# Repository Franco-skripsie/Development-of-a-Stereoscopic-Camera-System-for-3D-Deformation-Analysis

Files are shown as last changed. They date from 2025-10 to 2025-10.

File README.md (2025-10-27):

# Development of a Stereoscopic Camera System for 3D Deformation Analysis

This repository contains the hardware designs (CAD) and software for a custom stereoscopic camera system designed for 3D deformation analysis. The system uses two synchronized Raspberry Pi Camera Module 3 units to capture stereo image pairs, which can be used to compute depth information and analyze 3D deformation.

## Project Report
This repository supports the Mechatronic Project 478 final report. For a complete understanding of the project's background, design methodology, hardware selection, software algorithms, and full results, please read the complete PDF report.

View the Full Project Report `25866095-DuPlessis.pdf`

## Table of Contents

- [Overview](#overview)
- [Hardware Components](#hardware-components)
- [Software Components](#software-components)
- [Prerequisites](#prerequisites)
- [Installation](#installation)
- [Usage Guide](#usage-guide)
  - [1. Capturing Calibration Images](#1-capturing-calibration-images)
  - [2. Stereo Calibration](#2-stereo-calibration)
  - [3. 3D Dot Pattern Calibration](#3-3d-dot-pattern-calibration)
  - [4. Stereo Rectification and Disparity Mapping](#4-stereo-rectification-and-disparity-mapping)
- [Repository Structure](#repository-structure)
- [Calibration Patterns](#calibration-patterns)
- [Contributing](#contributing)
- [License](#license)

## Overview

This stereoscopic camera system is designed to:
- Capture synchronized stereo image pairs using dual Raspberry Pi Camera Module 3
- Perform accurate stereo calibration using both chessboard patterns and custom 3D dot patterns
- Generate disparity maps for depth estimation
- Enable 3D deformation analysis through precise depth measurements

The system features custom 3D-printed enclosures for camera protection, adjustable mounting, and optimized camera placement for stereoscopic imaging.

## Hardware Components

### Camera System
- **2x Raspberry Pi Camera Module 3** - High-resolution cameras with autofocus
- **Raspberry Pi 5** - Main controller for dual camera operation
- **Custom 3D-Printed Enclosures** (CAD files included):
  - `Camera Enclosure/` - Left and right camera housings with backplates
  - `RPi5 Enclosure/` - Protective enclosure for Raspberry Pi 5
  - `Base to Mounting Rail Connector/` - Hardware mounting system

### Calibration Equipment
- **Chessboard Pattern** - 9×6 inner corners, 14.5mm squares (for standard calibration)
- **Custom 3D Calibration Plate** - 264 white dots on black background:
  - Grid A: 143 dots (12×12 grid minus one) at -1mm depth
  - Grid B: 121 dots (11×11 grid) at reference plane (0mm)
  - 1.2mm dot diameter, 5mm spacing within grids
  - 1mm depth separation between grids for 3D calibration

## Software Components

The `Code/` directory contains Python scripts for the complete stereo vision pipeline:

### Calibration Scripts

1. **`stereo_calibration_collector.py`**
   - Interactive stereo image capture tool
   - Synchronized capture from both cameras
   - Live preview with crosshair alignment
   - Anti-flicker settings for LED lighting
   - Manual and timer capture modes
   - Quality validation and autofocus control

2. **`stereo_calibrate.py`**
   - Standard stereo calibration using chessboard pattern
   - Individual camera intrinsic calibration
   - Stereo extrinsic calibration (rotation & translation)
   - Outputs multiple formats: NPZ & JSON
   - Generates detailed calibration reports

3. **`stereo_calibrate_3d_dots.py`**
   - Advanced 3D calibration using custom dot pattern
   - Non-planar calibration for improved accuracy
   - Uses two grids at different depths (1mm separation)
   - Leverages proven chessboard calibration as initial estimates

### Dot Detection and Processing

4. **`dot_identifier.py`**
   - Automated white dot detection on black background
   - Processes custom 3D calibration plate images
   - Uses HoughCircles detection with white center validation
   - K-means clustering for column identification
   - Outputs sorted point arrays for Grid A and Grid B
   - Generates visualization and CSV export

5. **`live_dot_tuner.py`**
   - Interactive GUI for tuning dot detection parameters
   - Real-time parameter adjustment with visual feedback
   - HoughCircles parameter optimization
   - White center threshold tuning
   - Export optimized parameters for batch processing

### Stereo Processing

6. **`simple_stereo_rectify.py`**
   - Stereo image rectification
   - Epipolar line visualization
   - SGBM (Semi-Global Block Matching) disparity computation
   - Generates disparity maps (grayscale and color-coded)
   - Outputs rectified stereo pairs

## Prerequisites

### Hardware Requirements
- Raspberry Pi 5 (or compatible)
- 2× Raspberry Pi Camera Module 3
- Raspberry Pi SSD Kit (Recommended)
- Calibration patterns (printed or displayed)

### Software Requirements
- Python 3.7+
- OpenCV (cv2) with Python bindings
- NumPy
- Picamera2 (for Raspberry Pi Camera Module 3)
- Matplotlib
- Pandas
- scikit-learn
- Tkinter (for GUI tools)

## Installation

### 1. System Setup

```bash
# Update system packages
sudo apt-get update
sudo apt-get upgrade

# Install system dependencies
sudo apt-get install python3-pip python3-opencv
sudo apt-get install python3-picamera2
```

### 2. Python Dependencies

```bash
# Install required Python packages
pip3 install numpy opencv-python matplotlib pandas scikit-learn

# For GUI tools
sudo apt-get install python3-tk
```

### 3. Clone Repository

```bash
git clone https://github.com/Franco-skripsie/Development-of-a-Stereoscopic-Camera-System-for-3D-Deformation-Analysis.git
cd Development-of-a-Stereoscopic-Camera-System-for-3D-Deformation-Analysis/Code
```

## Usage Guide

### 1. Capturing Calibration Images

Use `stereo_calibration_collector.py` to capture synchronized stereo image pairs:

```bash
python3 stereo_calibration_collector.py
```

**Key Controls:**
- `c` - Capture stereo image pair
- `t` - Toggle between manual and timer modes
- `a` - Trigger autofocus on both cameras
- `l` - Lock white balance and autofocus
- `r` - Restore proven camera settings
- `q` - Quit

**Tips:**
- Capture 20-30 image pairs at different angles and distances
- Ensure the calibration pattern is clearly visible in both cameras
- Use the crosshair for alignment
- Vary the position and orientation of the pattern

### 2. Stereo Calibration

After capturing calibration images, perform stereo calibration:

```bash
python3 stereo_calibrate.py
```

This will:
- Detect chessboard corners in all image pairs
- Calibrate individual camera intrinsics
- Compute stereo extrinsic parameters (R, T)
- Generate rectification matrices
- Save calibration data: `stereo_calib.npz`, `stereo_calib.json`
- Create `calibration_report.txt` with detailed results

### 3. 3D Dot Pattern Calibration

For advanced calibration using the custom 3D dot pattern:

#### Step 3a: Detect and Sort Dots

```bash
# Basic usage
python3 dot_identifier.py --image path/to/image.png

# With custom parameters
python3 dot_identifier.py \
  --image calib/left001.png \
  --output results/left001 \
  --hough-min-dist 25 \
  --hough-param1 50 \
  --hough-param2 15 \
  --white-threshold 180
```

**Output Files:**
- `*_gridA_points.npy` - Grid A dot coordinates (143 points)
- `*_gridB_points.npy` - Grid B dot coordinates (121 points)
- `*_dots.csv` - All detected dots with grid/column/row info
- `*_visualization.png` - Visual verification of detection

#### Step 3b: Tune Detection Parameters (Optional)

Use the interactive tuner to optimize detection:

```bash
python3 live_dot_tuner.py --image path/to/image.png
```

The GUI allows real-time adjustment of:
- Minimum distance between circles
- Edge detection threshold
- Circle detection threshold
- Radius range
- White center threshold

#### Step 3c: 3D Calibration

After processing dot identification for stereo pairs:

```bash
python3 stereo_calibrate_3d_dots.py
```

This performs:
- Non-planar calibration using two grids at different depths
- Uses chessboard calibration as initial estimates
- Outputs: `3d_plate_stereo_calib.npz`, `3d_plate_stereo_calib.json`

### 4. Stereo Rectification and Disparity Mapping

Process stereo images to generate depth information:

```bash
python3 simple_stereo_rectify.py
```

**Configuration** (edit script):
```python
CALIB_FILE = "stereo_calib.npz"           # Calibration data
LEFT_IMAGE = "capture/left001.png"         # Input left image
RIGHT_IMAGE = "capture/right001.png"       # Input right image
OUTPUT_DIR = "results"                     # Output directory
```

**Output Files:**
- `rect_left.png` / `rect_right.png` - Rectified images
- `rect_left_lines.png` / `rect_right_lines.png` - Images with epipolar lines
- `epipolar_comparison.png` - Side-by-side view
- `disparity_gray.png` - Grayscale disparity map
- `disparity_color.png` - Color-coded disparity map

## Repository Structure

```
Development-of-a-Stereoscopic-Camera-System-for-3D-Deformation-Analysis/
│
├── Code/                                    # Python software
│   ├── stereo_calibration_collector.py      # Image capture tool
│   ├── stereo_calibrate.py                  # Chessboard calibration
│   ├── stereo_calibrate_3d_dots.py          # 3D dot pattern calibration
│   ├── dot_identifier.py                    # Dot detection and sorting
│   ├── live_dot_tuner.py                    # Interactive parameter tuning
│   └── simple_stereo_rectify.py             # Rectification and disparity
│
├── Camera Enclosure/                        # 3D printable camera housings
│   ├── Camera_Backplate.ipt                 # Camera mounting backplate
│   ├── Camera_Enclosure_Left.ipt            # Left camera enclosure
│   └── Camera_Enclosure_Right.ipt           # Right camera enclosure
│
├── RPi5 Enclosure/                          # Raspberry Pi 5 enclosure
│   ├── RPi5_Enclosure_Bottom.ipt            # Bottom enclosure part
│   └── RPi5_Enclosure_Top.ipt               # Top enclosure part
│
├── Base to Mounting Rail Connector/         # Mounting hardware
│   └── Base_Mounting_Rail_Connector.ipt     # Rail mounting connector
│
└── README.md                                # This file
```

**Note:** `.ipt` files are Autodesk Inventor part files. Open them with Autodesk Inventor or convert to STL for 3D printing.

## Calibration Patterns

### Chessboard Pattern
- **Size:** 9×6 inner corners
- **Square Size:** 15mm
- **Purpose:** Standard stereo calibration
- **Usage:** Print on flat, rigid surface or display on screen

### Custom 3D Dot Pattern
- **Total Dots:** 264 (143 + 121)
- **Grid A:** 12×12 grid (minus one dot at column 12, row 2)
  - Depth: -1mm (behind Grid B)
  - 143 dots total
- **Grid B:** 11×11 grid
  - Depth: 0mm (reference plane)
  - 121 dots total
- **Dot Properties:**
  - Diameter: 1.2mm
  - Color: White dots on black background
  - Spacing: 5mm within same grid
  - Depth separation: 1mm between grids
- **Purpose:** Advanced 3D calibration with non-planar target

## Workflow Summary

1. **Setup Hardware**
   - Assemble cameras in 3D-printed enclosures
   - Mount on stable base with appropriate baseline distance
   - Connect to Raspberry Pi 5

2. **Capture Calibration Images**
   - Use `stereo_calibration_collector.py`
   - Capture 20-30 chessboard image pairs
   - Optionally capture custom 3D dot pattern images

3. **Perform Calibration**
   - Run `stereo_calibrate.py` for standard calibration
   - Or process dots and run `stereo_calibrate_3d_dots.py` for 3D calibration

4. **Process Stereo Images**
   - Use `simple_stereo_rectify.py` to:
     - Rectify stereo pairs
     - Compute disparity maps
     - Analyze depth information

5. **Analyze Results**
   - Review calibration reports for accuracy
   - Examine disparity maps
   - Use depth data for deformation analysis

## Calibration Quality Indicators

### Good Calibration:
- RMS reprojection error < 0.5 pixels
- Horizontal epipolar lines in rectified images
- Smooth, continuous disparity maps
- Baseline distance matches physical measurement

### Signs of Poor Calibration:
- RMS error > 1.0 pixel
- Misaligned epipolar lines
- Noisy or discontinuous disparity maps
- Need more image pairs at varied angles

## Troubleshooting

### Camera Issues
- **Blank/dark images:** Check lighting, adjust exposure in `stereo_calibration_collector.py`
- **Sync issues:** Ensure both cameras are properly initialized
- **Focus problems:** Use autofocus (`a` key) or restore proven settings (`r` key)

### Calibration Issues
- **Low accuracy:** Capture more image pairs with better coverage
- **Pattern not detected:** Improve lighting, ensure pattern is flat and clearly visible
- **High RMS error:** Check for motion blur, improve pattern quality

### Dot Detection Issues
- **Too few/many dots detected:** Use `live_dot_tuner.py` to optimize parameters
- **Incorrect clustering:** Adjust `--hough-min-dist` parameter
- **False positives:** Increase `--white-threshold` value

## Contributing

Contributions are welcome. This is an open-source academic project, and improvements to the calibration algorithms, hardware designs, or documentation are appreciated. Please feel free to fork the repository, make changes, and open a pull request.

### How to Contribute:
1. Fork the repository
2. Create a feature branch (`git checkout -b feature/improvement`)
3. Make your changes
4. Test thoroughly with actual hardware
5. Commit with clear messages (`git commit -am 'Add feature'`)
6. Push to branch (`git push origin feature/improvement`)
7. Open a Pull Request

### Areas for Improvement:
- Additional calibration pattern support
- Real-time disparity computation optimisation
- Enhanced GUI for calibration workflow
- Automated quality assessment
- Integration with 3D reconstruction pipelines

## License

This project is licensed under the MIT License. See the (`LICENSE`) file for details.

## Acknowledgments

This stereoscopic camera system was developed for 3D deformation analysis research. The system combines:
- Standard stereo calibration techniques (Zhang's method)
- Custom 3D calibration patterns for improved accuracy
- Raspberry Pi Camera Module 3 for high-resolution imaging
- OpenCV for computer vision processing

---

**Last Updated:** 2025

**Hardware:** Raspberry Pi 5 + 2× Pi Camera Module 3  
**Software:** Python 3 + OpenCV + Picamera2

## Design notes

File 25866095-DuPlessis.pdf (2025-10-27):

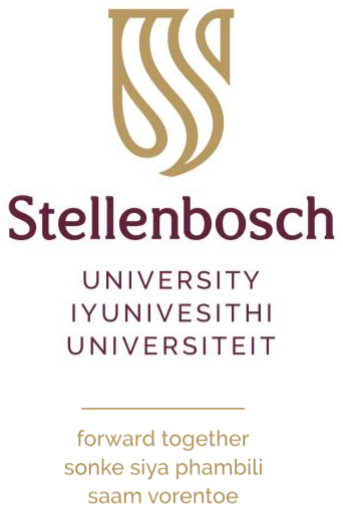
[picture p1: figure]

Department of Mechanical and Mechatronic Engineering Stellenbosch University
Tel: +27 21 808 4204 | www.eng.sun.ac.za
Private Bag X1, Matieland, 7602, South Africa

Copyright © 2025 Stellenbosch University All rights reserved

# Development of a Stereoscopic Camera System for 3D Deformation Analysis

## Mechatronic Project 478 Final Report

## F du Plessis

25866095

## Supervisor: Prof RP Theart

## October 2025

i

## Executive Summary

Title of Project
Development of a stereoscopic camera system for 3D deformation analysis.
Objectives
Objectives will focus on delivering a cost-effective final camera system that can be used for further research and development into the field of 3D digital image correlation (DIC):
1. To design and construct a cost-effective stereoscopic camera system suitable for researching and developing an in-house 3D DIC algorithm.
2. To develop a calibration procedure that is robust, user-friendly, and time-efficient, thus aiding in the overall experience when using the camera system.
3. To create an intuitive user interface that facilitates access to and execution of all relevant camera system functions.
What is current practice and what are its limitations?
The current systems available for conducting 3D DIC are from various corporate companies and are expensive. The systems are also closed-source in nature and do not provide the user with the ability to modify the software to cater to their specific needs. The software used has a poor user interface and a steep learning curve. This makes it overly complicated for most tasks that these systems encounter.
What is new in this project?
The project aims to develop a fully functional, open-source stereoscopic camera system optimised for Digital Image Correlation (DIC). The project offers a practical and scalable platform for experimentation, further research, and development. The project will feature stereo camera calibration, with an additional focus on using only one photo pair to complete the calibration procedure.
If the project is successful, how will it make a difference?
The system will provide the Mechanical and Mechatronic Department of Stellenbosch University with a portable and cost-effective stereoscopic camera system. The implementation of a user-friendly user interface will mitigate the steep learning curve, thereby ensuring that users can start capturing samples for material analysis quickly and easily. The camera system will allow the Mechanical and Mechatronic Department to develop and test their own fully open-source 3D DIC setup.

ii

What are the risks to the project being a success? Why is it expected to be successful?
The risks are a limited budget and time frame. The project's complexity is high and is associated with restricted access to the workshop of the Mechanical and Mechatronic Engineering Department. The project is expected to be successful due to the implementation of rigorous cost and time management. Additionally, careful scheduling of manufacturing will significantly contribute to the project's success.
What contributions have/will other students made/make?
N/A
Which aspects of the project will carry on after completion and why?
The project establishes a robust foundation for the Mechanical and Mechatronic Department to develop an in-house 3D DIC algorithm. It aims to deliver a fully functional, cost-effective, open-source 3D DIC system, designed to be accessible and adaptable for research and educational purposes. The calibration procedure developed can be applied to any other stereoscopic camera systems used at Stellenbosch University.
What arrangements have been/will be made to expedite continuation?
The system’s code and hardware designs will be uploaded to GitHub, ensuring it remains fully open-source and accessible for future development. Additionally, the hardware will utilise off-the-shelf components to streamline assembly and enhance scalability.

iii

## Plagiarism declaration

I have read and understand the Stellenbosch University Policy on Plagiarism and the definitions of plagiarism and self-plagiarism contained in the Policy [Plagiarism: The use of the ideas or material of others without acknowledgement, or the re-use of one's own previously evaluated or published material without acknowledgement or indication thereof (self-plagiarism or text-recycling)].

I also understand that direct translations are plagiarism, unless accompanied by an appropriate acknowledgement of the source. I also know that verbatim copy that has not been explicitly indicated as such, is plagiarism.

I know that plagiarism is a punishable offence and may be referred to the University's Central Disciplinary Committee (CDC) who has the authority to expel me for such an offence.

I know that plagiarism is harmful for the academic environment and that it has a negative impact on any profession.

Accordingly all quotations and contributions from any source whatsoever (including the internet) have been cited fully (acknowledged); further, all verbatim copies have been expressly indicated as such (e.g. through quotation marks) and the sources are cited fully.

I declare that, except where a source has been cited, the work contained in this assignment is my own work and that I have not previously (in its entirety or in part)
submitted it | for grading | in this | module/assignment | or another
module/assignment.

I declare that have not allowed, and will not allow, anyone to use my work (in paper, graphics, electronic, verbal or any other format) with the intention of passing it off as his/her own work.

I know that a mark of zero may be awarded to assignments with plagiarism and also that no opportunity be given to submit an improved assignment.

Signature

Name: | Franco du Plessis | Student no: 25866095
Date: | 09 March 2025

iv

## ECSA Exit Level Outcomes

ECSA Outcomes Assessed in this Module

ECSA Outcomes | Chapter Addressed
GA 1. Problem solving: Demonstrate competence to identify, assess, formulate and solve convergent and divergent engineering problems creatively and innovatively. | Chapter 1, 3, 4, 5
GA 2. Application of scientific and engineering knowledge: Demonstrate competence to apply knowledge of mathematics, basic science and engineering sciences from first principles to solve engineering problems. | Chapter 2, 3, 4, 5
GA 3. Engineering Design: Demonstrate competence to perform creative, procedural and non-procedural design and synthesis of components, systems, engineering works, products or processes. | Chapter 3, 4
GA 5. Engineering methods, skills and tools, including Information Technology: Demonstrate competence to use appropriate engineering methods, skills and tools, including those based on information technology. | Chapter 2, 3, 4, 5
GA 6. Professional and technical communication: Demonstrate competence to communicate effectively, both orally and in writing, with engineering audiences and the community at large. | Entire report
GA 8. Individual, Team and Multidisciplinary Working: Demonstrate competence to work effectively as an individual, in teams and in multi-disciplinary environments | Entire report
GA 9. Independent Learning Ability: Demonstrate competence to engage in independent learning through well-developed learning skills. | Entire report

v

## Table of contents

Page

vi

vii

C.2 Safety Report | 61
Appendix D Wiring Diagram of Relay Control | 68
Appendix E | Chessboard Pattern Calibration Report | 69
Appendix F | Single-Image Calibration Report | 70

viii

## List of figures

Page
Figure 1: Tensile Test Specimen Before and After Conducting a Tensile Test. ...... 6 Figure 2: The Setup for 2D and 3D DIC is Illustrated with Grayscale Observed Image on the Left and the Post-processed Results of the DIC on the

Figure 19: Chessboard Square Measured (left), Chessboard Fastened to Wooden

ix

Figure 28: Single Image of 3D Calibration Plate (left), Grayscale Conversion of
Image (right) | 46
Figure 29: Gaussian Blur Applied (left), Adaptive Thresholding Applied (right). . 47
Figure 30: Morphological Opening (left) and Closing (right) Applied | 47
Figure 31: Detected Circles Organised into Two Grids | 48
Figure 32: Gantt Chart of Completed Project | 59
Figure 33: Relay Control Circuit | 68
Figure 34: Chessboard Stereo Calibration Report | 69
Figure 35: Single-Image Calibration Report | 70

x

## List of tables

Page

## 1 Introduction

## 1.1 Background

Tensile testing is a fundamental and widely adopted method for evaluating the mechanical properties of materials under uniaxial tensile load. It provides critical insights into how a material behaves when subjected to stretching forces, including properties such as yield strength, ultimate tensile strength, and elongation (Saba et al., 2018). Although the behaviour of materials can be described mathematically to some extent, variations in composition, structure, and processing often lead to complex responses that cannot be fully captured through theoretical models alone. As such, tensile testing serves as an essential experimental approach for accurately characterising these properties and validating material performance in real-world applications.

This method utilises machines like the MTS Criterion C44 to apply a force to the sample, which can be monitored using the built-in load meter. During tensile testing, various methods can be used to collect point data that will be used to determine the material characteristics (AbouelNour et al., 2024). One of the most common methods employed uses a strain gauge that is physically attached to the specimen while performing a tensile test (Elmardi & Khayal, 2024).

Although strain gauges are a cost-effective solution to determining the properties of a material, they are only capable of measuring single-plane properties. Additionally, they must be physically attached to the point of measurement on the specimen to collect data (“Strain gauges”, n.d.) . This is undesirable when working with specimens whose surfaces are irregular or fragile, as it can lead to adhesion problems. Strain gauges are also sensitive to temperature changes and have a limited measurement range due to linear elongation (Shanmukha, 2017).

A solution to these limitations is to employ a method that does not require physical connections to the point of measurement, can accurately collect data of the specimen in multiple planes and remains a low-cost solution.

One possible solution is to use 3D Digital Image Correlation (DIC) analysis. DIC is a non-contact, image-based methodology used for measuring surface geometry, deformation, and strain, first established in the 1980s (Holmes et al, 2023). The sample is covered in a unique speckle pattern that is vital for the software to track any changes to the sample. DIC records a sequence of high-resolution images as the sample deforms, using mathematical algorithms to track surface displacement and extract deformation data. To achieve 3D analysis of a sample, the digital images are captured using a stereoscopic camera setup

(Zaremba & Nitkiewicz, 2024). This is achieved by using two cameras slightly angled toward each other, mimicking human vision. This setup creates a 3D representation of the sample’s surface, enabling full-field deformation analysis.

This analysis method requires three components: a stereoscopic camera setup, DIC software and a reliable calibration method. Currently, commercially available DIC systems, such as those from Correlated Solutions and LaVision, are prohibitively expensive, with costs exceeding R1 000 000. While the M&M Engineering Department at Stellenbosch University has two of these systems, access to these systems is limited. Concerns about potential damage to the equipment are a key reason for its infrequent use in undergraduate studies. The problematic and confusing user interface (UI) further emphasises the need for a new system. This highlights the need for a cost-effective, in-house developed alternative.

An open-source DIC system offers greater opportunities for researching innovative methods for conducting DIC and analysing speckle patterns. Full accessibility to the system is essential, enabling researchers to modify all relevant components as needed.

## 1.2 Problem Statement

The problem is that there is no accessible open-source stereoscopic camera system that allows accurate, low-cost 3D DIC analysis within the research and teaching environment.

## 1.3 Aim

The project will focus on designing and constructing a stereoscopic camera setup for conducting 3D DIC analysis. This setup will serve as a cost-effective alternative to the existing commercial systems while maintaining usability and accuracy.

The project aims to provide the Mechanical and Mechatronic Engineering Department with an additional DIC setup accessible to students from undergraduate to PhD levels. The scope includes developing the stereoscopic camera setup and designing a highly accurate and intuitive calibration procedure. This calibration process will be guided by intuitive and user-friendly interfaces, ensuring ease of use. Additionally, this system will be able to extract disparity maps of the analysed image scene. However, the development of the 3D DIC algorithm itself falls outside the scope of this project.

Unlike current commercial systems, this setup will feature an intuitive interface that simplifies operation and reduces the need for extensive training. As an in-house developed system, it offers flexibility for continuous improvement while reducing long-term costs associated with purchasing and maintaining commercial equipment. The open-source nature of the project enables anyone worldwide to access, build upon, and enhance the system, fostering collaborative innovation.

## 1.4 Objectives

The project will be defined by three main objectives, each with its own sub-objectives.

1. Physical System:
a. Design and construct a stereoscopic camera system that fits within an area of approximately 1 m³
to reduce the system footprint while operating.
2. Calibration Procedure:
a. Develop and implement a stereo camera calibration procedure that creates an accurate representation of changes in depth within an image scene.
b. Create the calibration procedure in such a manner that it can be completed within approximately 120 seconds from initiation to completion.
3. Control Software:
a. Develop optimised, user-friendly interfaces for navigating or conducting tasks when using the camera system. These interfaces will control all functions, including calibrating the system, capturing and storing images, and creating disparity maps of image scenes for analysis and interpretation.

## 1.5 Limits and Exclusions

The project has defined limits and exclusions to establish clear boundaries within which it will be conducted. The camera system will focus on tracking samples with sizes closely aligned with existing tensile testing standards (“Standard & specimens for metals tensile test”, n.d.). As a result, the system will be limited to tracking samples between 50 mm and 150 mm in both length and width. Although the system is capable of monitoring samples outside of this range, the project scope will be limited to the dimensions as mentioned above. This is because most tensile testing done to calculate material properties is conducted on samples that follow the ASTM standard, which are approximately the same size (“Standard & specimens for metals tensile test”, n.d.) The project will not utilise high-speed cameras, and therefore, the project scope will exclude high-speed testing. The cameras will operate at a maximum frame rate of 45 frames per second (fps). The cameras are capable of operating at a maximum frame rate of 56 fps at a resolution of 2304 × 1296 pixels (“Camera - Raspberry Pi Documentation”, n.d.). The limit of 45 fps allows adequate room for processing in the background while capturing images.

The project must be completed within the academic year and will operate within a maximum hardware budget of R5 500. The development of a 3D DIC algorithm is excluded to ensure project completion within the given timeframe. The project scope will not include the connection made between the tensile tester and the camera system.

## 1.6 Motivation

The motivation to conduct this project stems from the need to develop an in-house 3D DIC setup for the Mechanical and Mechatronic Engineering Department at Stellenbosch University. The system significantly reduces the initial capital cost compared to current commercial systems. Transitioning from these expensive commercial systems will free the Mechanical and Mechatronic Department from being restricted to using only specific replacement parts, which are often tied to the commercial system. Additionally, this reduces downtime caused by waiting for internationally shipped parts, which also incur import taxes. Beyond cost reduction, this project offers flexibility and customisation, enabling continuous improvements and adaptation to future developments in 3D DIC technology. Furthermore, the project allows the department to replicate the system, facilitating scalability and broader use across different research groups. Ultimately, the project establishes a solid foundation for future advancements in the 3D DIC field, particularly in terms of the potential development of an in-house, custom-designed 3D DIC algorithm.

## 1.7 Structure of Report

The report will start with a literature study talking about the project background, relevant components and previous work done in Chapter 2. The hardware design will be discussed in Chapter 3, with the analysis and motivation for design choices. Chapter 4 will analyse the software design and flow of information needed to achieve the full functionality required. The results will be examined in Chapter 5, along with the testing procedures followed to obtain them.

## 1.8 AI Usage in Report

This project was completed with assistance from AI. The use of AI was responsible, and everything in this report is the author's own work, unless otherwise indicated. AI was employed to correct spelling errors, improve grammar, and enhance the flow of paragraphs. It was also utilised to aid in understanding and analysing open-source code and its interactions.

## 2 Literature review

This chapter reviews the background, literature and previous work regarding stereoscopic camera systems. The elements discussed in this chapter will focus on the aspects related to the relevant implementation of 3D DIC.

## 2.1 Stereo Vision Background

Stereoscopic camera systems utilise two or more spatially separated image sensors to capture the same scene from different viewpoints. This arrangement mimics human binocular vision and enables depth perception through the principle of triangulation (Perumal et al., 2021). The fundamental physical assumption is that a single point in the real world will project to distinct pixel locations in each camera’s image plane. The difference in these pixel positions, referred to as binocular disparity (as discussed in Section 2.4), is used to infer depth (Anzai & DeAngelis, 2010). This process, which reconstructs three-dimensional geometry from two-dimensional images, is known as stereo vision (as discussed in Section 2.3), and forms the basis of spatial measurements in three-dimensional Digital Image Correlation systems (as discussed in Section 2.2).

## 2.2 Digital Image Correlation

Digital Image Correlation (DIC) is a technique that utilises digital images to measure the deformation of objects under stress. This non-contact method is widely used in fields such as materials science and engineering because it provides detailed data without requiring physical contact with the object. It is accomplished by continuously analysing the differences between two sequentially captured images. In practical engineering applications, DIC is employed to measure the deformation of specimens, such as the tensile test specimen seen in Figure 1, during tensile testing. This is done for varies reasons such as conducting quality control on manufactured samples, predicting the performance of materials to aid in material selection, and to compare materials during research and development.

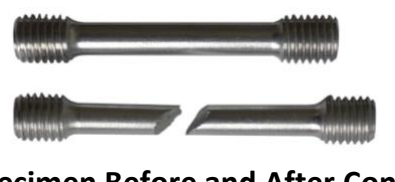
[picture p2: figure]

The DIC system captures images of the specimen’s surface at various stages as a controlled tensile force is applied. By analysing these images, DIC provides a full-field strain map that highlights how the material deforms, necks, or localisesstrain before failure. This detailed spatial data enables engineers to accurately

Figure 1: Tensile Test Specimen Before and After Conducting a Tensile Test.
Source: “Tensile test brittle deformation fracture”, 2021 determine critical mechanical properties, such as Young’s modulus, yield strength, and ultimate tensile strength. The DIC system requires data from the tensile tester, like tensile force, to conduct the deformation analysis. This creates a requirement for the camera system to be able to receive data from the tensile tester. The non-contact measurement capability of DIC ensures that the specimen remains unaltered during testing, thereby delivering reliable results necessary for material characterisation, product development, and safety assessment in real-world engineering scenarios.

DIC is primarily divided into two forms, 2D and 3D, both of which use a random speckle pattern during image analysis. The sample being analysed is covered in a random speckle pattern after the necessary surface preparations have been completed. The application of the speckle pattern is done using various methods like spray painting, spin coating and lithography, to name a few (Dong & Pan, 2017). The sample surface and background must have a high contrast to ensure optimal dot tracking conditions. This can be achieved by using a white background and black dots, for example. Consistent speckle size, typically 3-5 pixels in size, enhances spatial resolution, enabling more precise displacement measurements, especially when the sample is covered in an approximately equal distribution of white and black areas (“Fundamentals of Speckling for DIC”, 2023).

In DIC, the displacement of each speckle, represented by an individual point in the pattern, is measured as the distance it moves between consecutively captured images. The DIC software analyses this movement to determine the vector quantities of displacement. It tracks small regions of the image across successive frames by matching patterns to those in the reference image. This technique is applied across the entire image to monitor the displacement of all speckles during the deformation process. From this, normal, shear, and principal strains are determined. For 3D DIC, which measures depth and out-of-plane motion, two or more cameras are required to capture stereoscopic data (“Digital Image Correlation”, n.d.).

Two-dimensional DIC is limited to measuring in-plane deformations exclusively due to its single-camera setup. This approach is more straightforward and requires fewer computational resources compared to three-dimensional DIC. However, the technique is incapable of capturing out-of-plane displacements, which may result

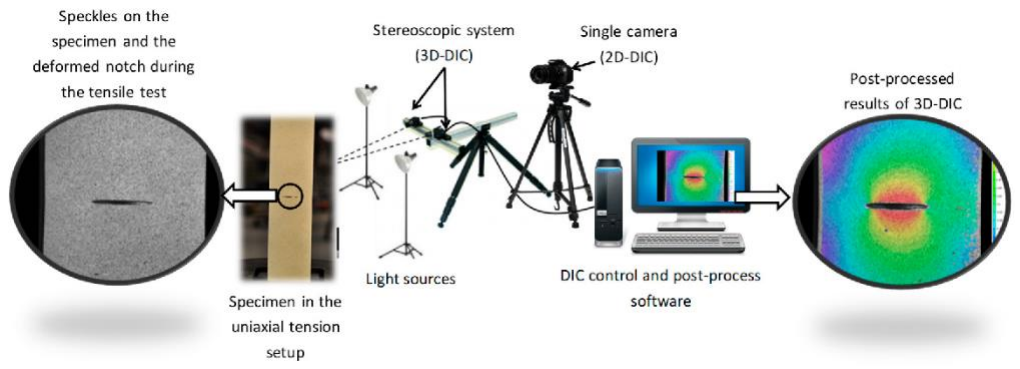
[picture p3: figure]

Figure 2: The Setup for 2D and 3D DIC is Illustrated with Grayscale Observed Image on the Left and the Post-processed Results of the DIC on the Right.

Source: “DIC and test set up”, 2018 in inaccuracies if the sample surface undergoes rotation or bending out of the plane (Sutton et al., 2008).

Three-dimensional DIC employs a multi-camera system to capture three-dimensional deformation, including out-of-plane movements, thereby facilitating more precise sample analysis. The intricacy of the setup necessitates meticulous and accurate calibration to attain optimal accuracy (Tiwari et al, 2007). The setup of 2D and 3D DIC can be seen in Figure 2, with an illustration of the elongation measured throughout the sample.

## 2.3 Stereo Vision Geometry

In a stereoscopic camera setup, the image measurements of each camera are given with respect to its own image coordinate system. To ensure accurate 3D spatial information, these measurements must be generalised to a single standard coordinate frame. A general representation of stereo vision geometry is shown in Figure 3, which illustrates the notation used in this report. To simplify calibration, the standard reference frame used by the system will be the same as the coordinate frame of the left camera.

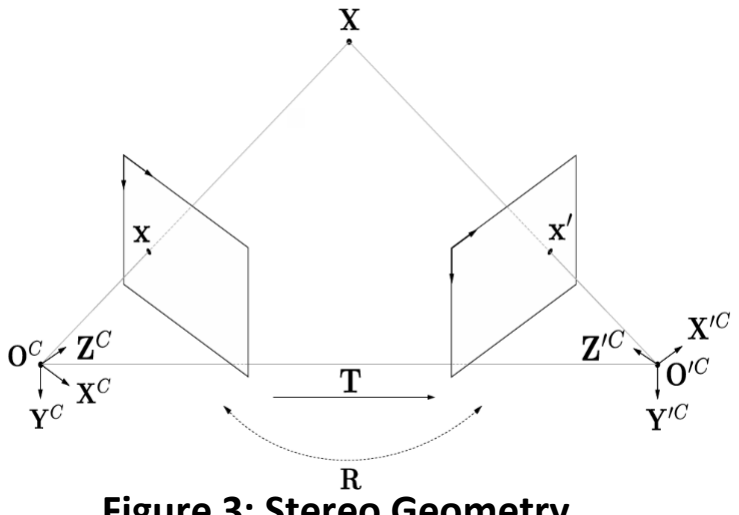
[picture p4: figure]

The centre of the left and right cameras’ optical sensors is defined as OC
and O′

C
respectively. Furthermore, the left camera’s coordinate system is indicated by X

C
,
Y

C
and Z

C
and has a real point X projected onto the image plane as x. Similarly, the right camera’s coordinate system is indicated by X′

C
, Y′

C
and Z′

C
and has a
projected point x’. Relative translation and relative rotation are indicated by T and R respectively. The relative rotation is the transformation that allows the alignment of one camera with another, expressed as a 3x3 matrix. The relative translation indicates the positional difference between the optical centres of the cameras, expressed as a 3D vector. These two parameters represent the extrinsic camera parameters and will be determined using stereo calibration. Baseline (B) is the distance between the centres of the two cameras’ optical sensors. The distance between the camera’s sensor and lens is known as the focal length (f),

Figure 3: Stereo Geometry

Source: “Generic representation of the stereo geometry”, 2017 measured in millimeters. Focal length can also be expressed in pixel units as fx and fy and is used to scale the world coordinates into the image plane.

## 2.4 Binocular Disparity

Binocular disparity is the horizontal offset between projections of the same 3D point onto two horizontally separated camera sensors. When you view a scene with two cameras, each camera sees the world from a slightly different angle. The difference in pixel coordinates of a feature between the left and right images is its disparity (Young, 2020).

To calculate the disparity (d) of pixels in an image, it must first be established which pixel in the image on the right matches a given pixel in the left image (“Depth Chapter 11”, n.d.). This can be completed using several methods, such as block matching (BM), semi-global block matching (SGBM), and feature-based matching (“OpenCV”, n.d.). In this report, SGBM will be used due to its increased accuracy and parameter tuning capabilities (“OpenCV”, n.d.). SGBM has a total of 11 parameters, compared to feature-based matching, which has five parameters, and block matching, which has two parameters. This is why SGBM was selected.

After the corresponding points have been identified, using SGBM, sub-pixel enhancement can be applied to boost depth precision (“OpenCV”, n.d.). The enhanced data can be used to calculate the disparity using Equation 2.1.

d = xL − xR | (2.1)

The left pixel’s horizontal location is represented by xL and the pixel on the right by xR. Thus, the disparity (d) is the difference between the two projected points on the image frame. After the disparity is calculated, the triangulation equation can be applied to compute the real-world depth of each point (“Depth Chapter 11”, n.d.).

Z =

f∙B d | (2.2)

In Equation 2.2, Z refers to the depth along the camera’s optical axis measured in milimeters.

## 2.5 Camera Calibration

To achieve an accurate correlation between 3D real-world points and 2D image points on an image, we must apply camera calibration. This process is characterised by calculating the intrinsic and extrinsic camera parameters. Intrinsic parameters describe the internal optics of the camera, including focal length (fx, fy) and principal point (cx, cy), both of which is measured in pixels.

Extrinsic parameters, on the other hand, define the camera’s position in the real world relative to a reference coordinate system, like its rotation and translation (Hartley & Zisserman, 2004).

Calibration is done to account for and correct the imperfections found in the cameras’ lenses and sensors, ensuring accurate measurements. Accurate calibration ensures a highly accurate representation of real-world properties.

A calibration object is used to define real-world coordinates of 3D points, such as a checkerboard or calibration plate, with known dimensions. The cameras capture the images of the calibration plate and find the pixel coordinates (u, v) for each 3D point. The intrinsic and extrinsic camera parameters are calculated using a camera calibration algorithm.

### 2.5.1 Intrinsic Parameters

The focal length (measured in pixels) indicates the distance between the optical centre and the image plane, adjusted according to the pixel dimensions of the sensor. The principal point is the pixel coordinate where the camera’s optical axis intersects the image plane, typically located near the centre of the image. The focal length and principal point are expressed in a matrix called the intrinsic matrix (K), shown in Equation 2.3. The skew parameter (s) is generally assumed to be zero for most cameras and can usually be ignored (“Pinhole Camera Model”, n.d.).

K = [

fx | s | cx
0 fy | cy
0 | 0 | 1

] ≈ [

fx | 0 cx
0 fy | cy
0 | 0 | 1
] | (2.3)

### 2.5.2 Extrinsic Parameters

Extrinsic parameters define the spatial relationship between the camera and the world coordinate system. They consist of a rotation matrix (R) and a translation vector (T), which together transform 3D points from the real-world coordinate system into the camera coordinate system. Rotation (R) is a 3×3 matrix that specifies the orientation of the camera with respect to the reference coordinate system. It determines how the camera is “pointing” in space. Translation (T) is a 3×1 vector that defines the position of the camera centre relative to the world origin. It describes the location of the camera (Anwar, 2022).

The combination of R and T allows us to map a point from world coordinates (X

W,
Y

W, Z

W) into the camera coordinate system, using Equation 2.4.
[

X

C
Y

C
Z

C

] = R [

X

W
Y

W
Z

W

] + T | (2.4)

This step is pivotal as it aligns the world coordinate system, defined by the calibration object, with the camera’s coordinate system, thereby enabling the correlation of real-world geometry with image measurements.

## 2.6 Design Choice for Computer Platform

The camera system must be able to operate independently, capturing and processing images without requiring external assistance. To achieve this functionality, the camera system requires its own computing system. Multiple options can be taken to achieve this outcome, for instance: Microcontroller or Single-Board Computer (SBC). Each of these options has its own advantages and disadvantages. For this project, the SBC was the most suitable choice for achieving the desired outcomes due to the following reasons. The average processing power of microcontrollers is considerably less than that of an SBC. The CPU, RAM and storage capabilities of microcontrollers are also inferior to those found in most SBCs. These are crucial for the smooth operation of any stereoscopic camera system. Another benefit of the SBC is that it runs a whole operating system, which introduces the ability to run high-level programming languages like Python and C++ (“The Comparison between Microcontrollers and Single board Computer”, 2024). The versatility and enhanced connectivity options established SBCs as the optimal choice for this project. In the future, the SBC will also connect to a laptop or computer to utilise its additional processing power for conducting 3D DIC. DIC.

### 2.6.1 Single Board Computers

Single-board computers (SBCs) are self-contained computers built on a single circuit board. They are characterised as being compact, versatile and affordable. SBCs integrate all the essential components needed to function as a computer onto a single board. They have their own processor, memory, storage, and input-output interfaces, and only require a display, power connection, and navigation peripherals to function as a standalone computer. Most SBCs are not only limited to being used as a computer but also support expansion ports for adding features (Arun KL, 2023). This will benefit the system's future use in 3D DIC, where the tensile tester can transmit valuable data, like tensile force, to the SBC via the GPIO pins. The process of choosing the most suitable SBC will be discussed in Section 3.1.

## 2.7 Previous Work Done

The system developed in this project is inspired by LaVision’s commercial digital image correlation (DIC) system, StrainMaster, which is used to measure sample deformation, as seen in Figure 4. The LaVision system supports both 2D and 3D DIC and is operated through its proprietary software, DaVis, which manages all system functionalities (“LaVision DaVis 11”, n.d.). It features a stereo camera setup with a modular design, consisting of a rail mounted on a bipod, equipped with movable lights and cameras. The system can perform multiple calibration methods, including the use of a chessboard or a custom 3D calibration plate. The 3D calibration plate has a height difference that allows the system to calibrate a stereo camera pair using a single image by leveraging the disparity in depth between the two levels.

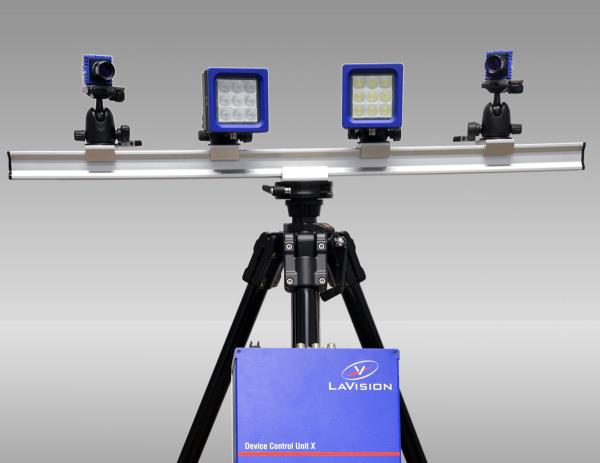
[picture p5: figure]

## 2.8 Chapter Summary

This chapter provided the literature needed to comprehend the concepts used throughout the project. The next chapter will discuss the hardware design choices made during the process of creating the stereo camera system.

Figure 4: LaVision StrainMaster.

Source: “StrainMaster-portable”, n.d.

## 3 Hardware Design:

This chapter will discuss all the choices made during the process of designing and creating the hardware used in this project. The components that will be discussed are used to create a stereoscopic camera system. The section will include a discussion of the single-board computer, cameras, system frame, lighting, storage and component enclosures.

## 3.1 Selecting a Single Board Computer

The world of single-board computers (SBCs) is extensive and caters to all requirements. The four main criteria to consider when selecting one are: processing power, input/output (I/O) ports, expansion capabilities, and price range. Each criterion is chosen for specific reasons. Processing power is essential because the SBC must be capable of capturing, processing, and analysing data on the system. I/O ports are crucial, as they enable the user to connect peripherals to the SBC easily. Peripherals may include, but are not limited to, a computer screen for data display, as well as a USB wired or Bluetooth mouse and keyboard for navigating the central control software. A crucial aspect of the I/O ports is the presence of general-purpose input/output (GPIO) pins. These pins are fully programmable and can be used to send or receive electrical signals (Butler, 2022). For this project, the GPIO pins will control the lighting of the camera rig. In the future, the pins could be utilised to read data from external equipment such as load cells or extensometers, assisting in the development of the 3D DIC system.

Expansion capabilities, because the system will require specific additional expansion components to achieve the end goal of having a stereoscopic camera system. These expansions may include installing an SSD kit to enhance storage speed and increase overall capacity or adding cameras to establish the stereoscopic camera setup needed for this project. The system is being developed to a specific operational standard while keeping future possibilities in mind, especially in case someone else takes over and expands it further. Price range, because the project is focused on creating a budget-friendly stereo camera system, and the computing units are one of the most expensive components in the system.

In Table 1, a few of the options that were considered for the SBC will be listed along with their relevant specifications. The criteria mentioned above were used to select an SBC system that would achieve the project's outcome.

The three candidate SBCs differ notably in processing power and memory. The Raspberry Pi 5 (RPi 5) can be equipped with RAM ranging from 2 to 16 GB and features a 2.4 GHz quad-core CPU, providing ample headroom for running a high-resolution camera system. The additional memory enables smoother handling of image buffers and video streams. The Raspberry Pi 4B, by contrast, features a range of 1 to 8 GB of RAM and a quad-core CPU at 1.5 GHz, providing adequate but more limited performance for demanding imaging tasks. The BeagleBoard BeagleY-AI integrates 4 GB of RAM and a 1.4 GHz quad-core processor, offering less raw performance and memory capacity than the RPi 5, which may limit scalability when managing larger datasets or higher frame rates.

This project requires an SBC that has two CSI ports for cameras to facilitate stereoscopic vision, an Ethernet port to connect to a wired internet connection if needed, and multiple USB ports to navigate the SBC. The presence of dual CSI ports is one of the most important properties that the SBC must have, a vital feature required to connect two cameras simultaneously for the stereo camera system, essential to achieving stereoscopic vision in this project. The USB ports are needed to ensure the system has a robust user navigation method, allowing for the physical connection of peripherals such as keyboards and mice, providing robust connectivity. Additionally, the SBC should support the possibility of remotely logging in and controlling the SBC via protocols such as SSH or VNC, thereby enhancing accessibility without requiring physical interaction. The Ethernet port is also necessary to ensure system robustness, providing a reliable fallback for network connectivity when Wi-Fi is unavailable. Furthermore, the presence of an HDMI port allows the user to connect a display to operate the SBC and conduct all the necessary steps, such as setup, configuration, and troubleshooting.

The SBC must feature adequate expansion capabilities, including the presence of GPIO pins and provisions for SSD upgrades. The presence of GPIO pins is a vital requirement for user customisation in the open-source system design, ensuring that the system can be altered to fit a specific scenario. The GPIO pins can also be used to control key system components from a central control software, like turning on lights for improved sample clarity. Furthermore, the SSD upgrade capability is essential to increase the speed at which photos and videos can be saved, while also boosting overall storage capacity. Both the Raspberry Pi 5 and the BeagleBoard BeagleY-AI feature a PCIe connector, allowing for the connection of a fast SSD.

Table 1: Single-Board Computer Specification Comparisons
Parameter | Raspberry Pi 5¹ | Raspberry Pi 4B² | BeagleBoard BeagleY-AI³
Processing Power | Quad-core processor @ 2.4 GHz 8 GB LPDDR4 RAM | Quad-core processor @ 1.5 GHz 8 GB LPDDR4 RAM | Quad-core processor @ 1.4 GHz 4 GB LPDDR4 RAM
I/O Ports | 4 x USB 2 x microHDMI 1 x Gigabit Ethernet | 4 x USB 2 x microHDMI 1 x Gigabit Ethernet | 4 x USB 1 x microHDMI 1 x Gigabit Ethernet
Expansion Capabilities | 40-pin header 2 x MIPI CSI ports | 40-pin header 1 x MIPI CSI port | 40-pin header 2 x MIPI CSI ports

“Raspberry Pi”, 2025
“Raspberry Pi”, 2025
“Mouser Electronics”, 2025

Parameter | Raspberry Pi 5¹ | Raspberry Pi 4B² | BeagleBoard BeagleY-AI³
| PCIe FFG Connector | | PCIe FFG Connector
Price Range | ± R1 680 | ± R1 580 | ± R1 455

Given the primary emphasis of the project on cost-effectiveness, the selected SBC must strike a balance between affordability and delivering all essential features without unnecessary extravagance. This ensures that resources are optimised, particularly in an open-source environment where scalability and value for money are paramount. The pricing of SBCs is intrinsically linked to their performance metrics, processing power, and integrated capabilities.

Among the options considered, the Raspberry Pi 5 stands out as the most expensive variant, with prices around R1 680. It is closely followed in cost by the Raspberry Pi 4 Model B, which retails at approximately R1 580. In contrast, the BeagleBoard BeagleY-AI emerges as the most affordable option, available for around R1 445. However, despite its attractive pricing, the Raspberry Pi 4B falls short in key areas, notably lacking dual CSI ports. This limitation renders it unsuitable, as it would necessitate additional hardware workarounds that could compromise cost-effectiveness and system simplicity.

Ultimately, the slower processing speed of the BeagleBoard BeagleY-AI and the smaller community support did not justify the savings made when choosing this option, despite its dual CSI ports. Keeping in mind that the system must be future-proof, the Raspberry Pi 5 was selected as the chosen SBC for this project.

## 3.2 Selecting Cameras

Choosing the right cameras is essential for the project's success. Cameras serve as the primary connection between the real world and the data processed by the software via the single-board computer. The cameras that will be used in this project must integrate seamlessly with the chosen SBC. The Raspberry Pi 5 features four USB ports and two CSI ports, all of which can be used to connect cameras. The USB ports of the RPi 5 are split, two of them are USB 3.0 ports and the other two are USB 2.0 ports. This difference is an important characteristic to keep into account when deciding on the correct USB camera, because of the speed difference between the USB 3.0 and USB 2.0 ports. It is required that the cameras be exactly the same model; this helps the system to use the same method to communicate and control the cameras.

Although multiple suitable USB cameras are available, this project will restrict the system to use only cameras that connect to the RPi 5 through the CSI ports. This was decided because of the ability to synchronise the frames captured by the cameras using the CSI ports. It is crucial for the stereoscopic camera systems to capture synchronised frames during 3D DIC to ensure accurate calculations. The higher bandwidth provided by the CSI ports along with the lower latency made it far superior than USB cameras.

Several cameras communicate using an FFC that connects to a CSI port. To make the camera system user-friendly, the camera must have autofocus. This requirement ensures that the user can achieve perfect image focus through software alone, without physically adjusting the camera. Cameras without autofocus require the user to manually adjust the lens until the desired focus is achieved, adding extra steps that can cause difficulties. Depending on the overall camera system setup, it can be challenging to monitor outputs while adjusting focus. It may also result in moving the system during adjustments, which could affect the accuracy of results in successive tests.

Raspberry Pi offers a variety of camera modules that can connect to the RPi 5 via the CSI ports. The Camera Module V2 was launched in 2016 and features an 8-megapixel camera, but it is limited to manual focus only. Its successor, released in 2023, is the Camera Module V3, which has a 12-megapixel camera and includes autofocus. The Camera Module V3 comes in four different models with various features, such as standard and wide-angle lenses, as well as infrared options. Raspberry Pi also provides two camera modules with lens mount options. The High-Quality Camera model offers two lens mounting options, the CS- and M12-mount variants. Both of these cameras have manually adjustable focus, which disqualifies them for this project.

ArduCam is another big provider in the camera scene for SBCs. They offer options like the ArduCam PTZ camera controller module, which, when paired with their 8MP IMX219 camera, provides a system with autofocus and a replaceable lens. This feature would be a bonus, enabling the cameras to zoom in on the object during testing. Unfortunately, this module does not work with all the camera libraries utilised in this project and falls outside of the budget with a price of R1 647 per camera (“RobotShop”, n.d.). Another module that fits the requirements is the ArduCam 12MP 477P autofocus high-quality camera module. This module features autofocus and an M12 lens mount, but unfortunately, it falls outside of the budget with a price of R1 855 per camera (“12.3MP Motorized Focus Camera Module for Raspberry South Africa”, n.d.).

This project will utilise the Raspberry Pi Camera Module V3 configured with the standard lens and an IR filter. This option falls precisely within the project's budget and includes all the required features. The standard option is chosen above the wide-angle option to ensure that the best resolution image of the sample is captured. This project will not benefit from the NOIR module due to it operating under the controlled illumination provided by the lights as discussed in Section
3.5. The Sony IMX708 sensor has a resolution of 4608 x 2592 pixels and a FOV of 75 degrees. The camera module is capable of capturing a smooth 56 fps at a resolution of 2304 x 1296 pixels, which is good when the camera system is used to conduct 3D DIC.

## 3.3 Storage Expansion

The camera system would benefit from additional storage to increase the amount of data that can be captured on the device, as well as an improvement in read and write speeds. The faster images and videos can be saved to the storage, the quicker the software can start analysing the saved data. The micro SD card was tested using the built-in SD card speed test and showed a sequential write speed of 72 037 KB/s. The price of a 512 GB U1 micro SD card is R1 099 and will, in theory, improve the write speed. The cost of a Raspberry Pi 512 GB SSD kit is R1 150, just over R50 more than the micro SD card, while increasing the sequential write speed to 859 488 KB/s. Each camera captures a video feed of 2304x1296 pixels at 45 fps. This corresponds to a total required writing speed of 393 660 KB/s per camera, or a combined writing speed of 787 320 KB/s. By expanding the storage of the Raspberry Pi 5 with a faster SSD kit, the project will not be limited by storage speed.

## 3.4 Stereo-Rig Frame

The system's frame acts as the backbone to which all components are attached. It must have a rigid structure to ensure consistency during use, while also maintaining modularity to adapt to various situations the system might face. This section will be divided into three parts: the mounting rail, the base, and the connection between them.

### 3.4.1 Mounting Rail

To ensure the system has a solid backbone, all components must be connected to a single rigid piece. This piece must have enough flexibility to allow all components to be connected and adjusted to suit the intended application. An aluminium extrusion was selected for its rigidity, lightweight nature, and widespread availability. The specific dimensions chosen for this project are 20x20x1 000 mm. This helps keep costs and weight low while providing the necessary rigidity for the mounting rail. Many products are available for 20x20 aluminium extrusions, making future upgrades or extensions to the mounting rail easier.

### 3.4.2 Camera Base

The camera system needs a secure base for attachment. The base should be adjustable enough to adapt the system for different scenarios. The project will use an adjustable tripod as a stable foundation that can be configured for various situations. The tripod features a built-in bubble level to assist the user in levelling the camera system. When folded, the tripod measures 350 mm long, making it easy to store, and it can extend to a height of 1 020 mm.

### 3.4.3 Connector Between Base and Mounting Rail

The system must include a connecting piece between the aluminium extrusion and the tripod base. This ensures that the stereo-rig frame functions as a single solid unit. The connector is designed using Autodesk Inventor Professional 2025 and is 3D printed with Polylactic Acid (PLA) for this project. However, it is not limited to being made from PLA alone. The connector can be machined from metal if increased rigidity or durability is needed. It features three holes: two for mounting to the aluminium extrusion with T-bolts, and a third for attaching to the tripod. The tripod connection hole will incorporate a threaded brass insert to guarantee a secure and robust connection. The threaded brass insert can be added with the use of a hot soldering to melt the plastic. The connection piece can also be used to attach the aluminium extrusion to a different base or even the tensile tester itself with custom extensions.

## 3.5 Lighting and Control

When capturing photos and analysing samples, consistent lighting is essential for reliable and accurate results. The system should include its own illumination, providing sufficient light regardless of ambient conditions. To prevent damage to the Raspberry Pi, the lighting control circuit must be isolated from it, yet still manageable via the Pi’s GPIO pins.

For this project, two 10 W LED flood lights, each producing 1 000 lumens, will be used. Their small size and affordability align well with the project's goals. Powered by 220 V, they require a relay circuit to be safely controlled by the system through the GPIO pins. The power extension cord providing power to the RPi 5 power supply has two 3-point plugs, allowing for an additional connection for the 220V lights. An off-the-shelf 2-relay module, known for its simplicity and compactness, was chosen. It operates at 5 V DC and can handle 10 A at 250 V AC per relay. An external 5V supply will power the relays to protect the GPIO pins. Control will be via two GPIO pins on the Raspberry Pi (GPIO 14 and 15), designated for the left and right lights. The control circuit is isolated from the high voltage side. Refer to Figure 33 for the connection diagram in 5.7Appendix D

## 3.6 Component Enclosures

This section discusses the enclosures developed or chosen for the camera system components. The first enclosure addressed is the one designed for the Raspberry Pi 5. Although many enclosures are available for the RPi 5, none meet the specific requirements of this project. Commercial options, such as the official RPi 5 case or the Argon NEO 5 case, each have limitations. The official RPi 5 case lacks the mounting options needed to attach it to the aluminium extrusion. Additionally, its lid cannot close once the SSD kit has been installed (“Raspberry Pi Case for Raspberry Pi 5”, 2024). The Argon NEO does not facilitate routing the camera cables, rendering it unsuitable for this project. The Raspberry Pi community has created multiple CAD files suitable for 3D printing, enabling custom fitting for various projects, such as building a desktop PC or attaching to the back of a monitor. None of the cases that were found suited the intended use case for this project.

A RPi 5 case was designed in Autodesk Inventor Professional 2025 to meet specific requirements. These include allowing the SSD kit to be mounted onto the RPi 5 while remaining enclosed, providing sufficient space for routing camera cables from the RPi 5 and the cameras, incorporating appropriate mounting options to secure the case to the aluminium extrusion, and ensuring adequate ventilation and port access.

The case will be 3D printed due to its cost-effectiveness and easy accessibility. The decision to use 3D printing also aims to keep the project on an open-source track. This allows anyone with access to a 3D printer to produce the case, even if they are not working on this specific project. The process begins by converting a 3D model into G-code, a format readable by 3D printers. Filament is then heated to its melting point and laid onto the print bed according to the G-code instructions. This process is repeated layer by layer until the object is complete. The plastic selected for this project is Polylactic Acid (PLA) due to its affordability, ease of use, and material properties (Carlota, 2023). The case will not encounter significant forces and will stay below the glass transition temperature of 65 ºC for PLA. Other common filaments are either difficult to print, like ABS, or very expensive, like PA12-CF Nylon.

The enclosure for the Raspberry Pi Camera Module V3 had the same problems as the RPi 5 case. The lack of commercially available options, joined with the existing CAD models, led to the design of a custom camera enclosure. This camera enclosure must fit the Raspberry Pi Camera Module V3 snugly, protect all the circuitry and lens mechanisms inside and allow for adjustable mountings to the aluminium extrusion. The enclosure was also designed using Autodesk Inventor Professional 2025 and 3D printed out of PLA for the same reasons as the RPI 5 case. The 3D-printed enclosures can be viewed in Figure 5.

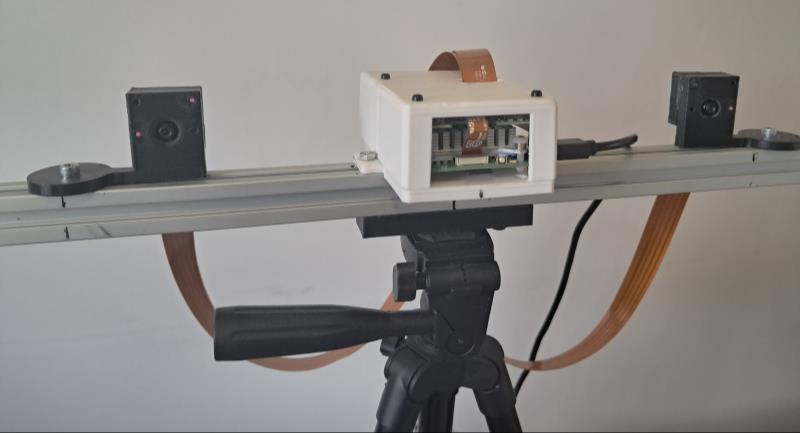
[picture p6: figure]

The final enclosure is for housing the electronics responsible for controlling the lights, as seen in Figure 6. Due to the circuit operating with 220 V and having live exposed contacts, the enclosure must be capable of reliably and safely isolating the electronics from everything in its surroundings. To mitigate the risk of a faulty 3D printing part posing a potential threat, the enclosure must be an off-the-shelf component rated to handle 220 V. To ensure that the enclosure meets these requirements, the Ingress Protection (IP) rating will be used as guidance. The IP rating guidelines indicate the level of protection of an electrical enclosure against the environment. The rating starts with IP and then leads with two numbers, the first indicating the protection against solids and the second against water. The enclosure must protect against, at a minimum, any solid objects entering the enclosure and against water splashing onto it. To satisfy these requirements, the enclosure must at least be rated to IP 44. The enclosure that was chosen is rated to IP 55, due to the extra protection against dust and water (Luke, 2013). This will ensure that the electronics remain completely protected against dust and water during operation. The CAD files can be downloaded by following this link (https://github.com/Franco-skripsie/Development-of-a-Stereoscopic-Camera-System-for-3D-Deformation-Analysis) to the GitHub page.

Figure 5: 3D Printed Enclosures.

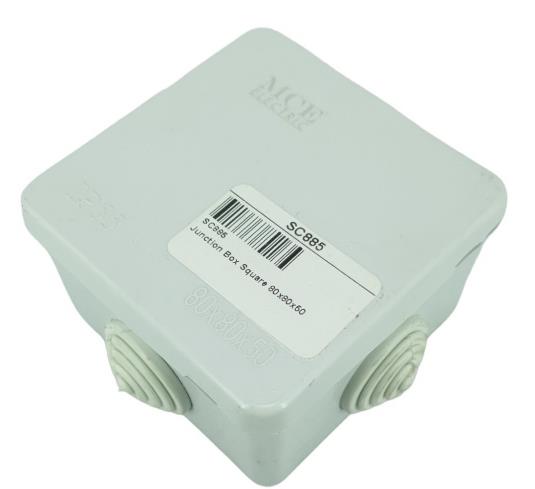
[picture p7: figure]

Figure 6: Electronics Enclosure.

Source: “Junction Box Square”, 2025

## 3.7 Constructed Hardware System

Figure 7 illustrates the entire physical system after combining all of the hardware into one camera assembly.

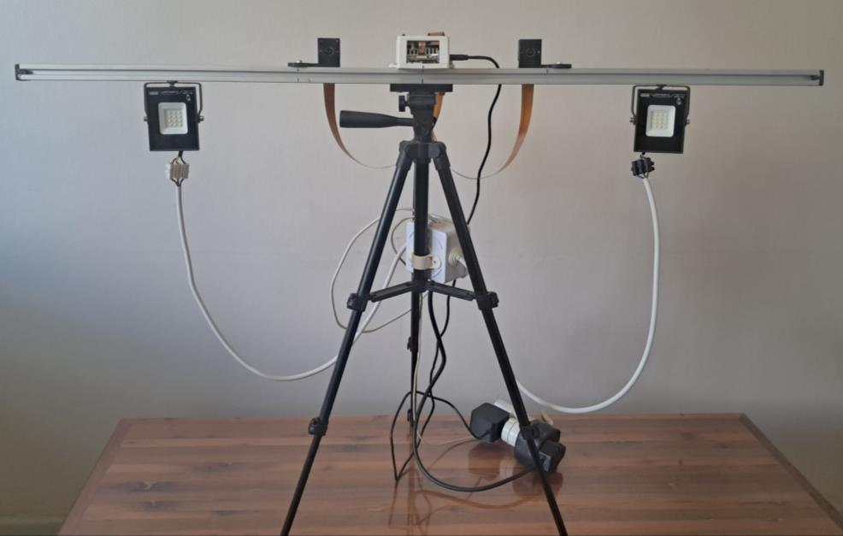
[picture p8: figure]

## 3.8 Chapter Summary

This chapter discussed the hardware design of the camera system created in this project. The choices that were made in picking components and materials where adequately provided and motivated. This ensures that the reason for the hardware is sufficient if someone would reference back to this report without any context. The next chapter will provide the software design choices made in this project.

Figure 7: Camera System Used in this Project.

## 4 Software Design:

This chapter covers all the software design choices and optimisations made during the project's development. Each aspect of the process will be examined individually, beginning with image capturing. The calibration process will follow, then image rectification and disparity mapping. The section will end with a discussion of how single-image calibration will be implemented. Figure 8 illustrates the flow of the software implemented in this project.

## 4.1 Image Capture

This code provides image acquisition functionality for a stereo camera calibration system built with a Raspberry Pi 5 and two Raspberry Pi Camera Module V3 devices. Its primary purpose is to capture synchronised, high-resolution stereo image pairs of a calibration target under controlled exposure and focus conditions. These images form the essential dataset for calibrating the geometric and optical parameters of the stereo camera setup, enabling the accurate construction of disparity maps.

The relatively new Raspberry Pi Camera Module V3 can be controlled by Python software libraries like libcamera or Picamera2. Libcamera is an open-source camera stack designed for various platforms, featuring a core user space library supported by Linux kernel application programming interfaces (APIs) and drivers. It simplifies the complexity of embedded camera hardware by offering an intuitive API and separating untrusted vendor code from the open-source core (“libcamera”, n.d.). Picamera2 is built on top of the open source libcamera project by directly using the Python bindings supplied by libcamera. This is done to simplify the experience when using Raspberry Pi applications compared to libcamera’s own bindings (The Picamera2 Library, 2022). This project will use Picamera2 to control the two Raspberry Pi Camera Module V3’s due to the added simplicity when working with all Raspberry Pi components.

The process starts by initialising the two cameras and sets them up for high-resolution still captures. The cameras are set to capture at their maximum resolution of 4608 x 2592 pixels. This is done to maximise the resolution for not only the future steps during the calibration process, but also for the end goal of applying 3D DIC. The cameras have a 2-second delay before they can be used to allow the auto-exposure and white balance to stabilise. This is implemented to prevent early-frame inconsistencies during the stabilisation period.

Figure 8: Flow of Software Implementation.

Due to the camera system using two LED flood lights, the cameras experience a phenomenon known as the strobe effect. This effect is caused by the misalignment of how vast the camera shutter opens and closes, as well as how fast the LED is turning on and off (“Crushing Photography”, n.d.). The alternating cycle of the LED turning on and off is caused by it being powered by a 50 Hz alternating current, as found in South Africa. This means that the LEDs flicker a total of 50 times per second. To compensate for this effect, Picamera2 has built-in functions that are able to handle this effect. The first function is called AeFlickerMode() which must be set to 1. This indicates to the library that the code will utilise functions to combat the flickering. The next function is called AeFlickerPeriod() and indicates to the system what the desired flicker period is. Due to the LEDsflickering 100 times per second the period must be 5 000. This indicates that the flicker period is 10 ms. The final setting that must be changed is the cameras ExposureTime. This helps with aligning the cameras shutter speed with the LEDs flickering rate. The exposure time must be a multiple of the shutter speed (1/50s). Testing the camera rig indicated that the ExposureTime must be set to
10 000.

After the cameras have been successfully initialised, they remain ready until all the photos have been successfully captured, or the program is terminated. The cameras capture images in the RGB (Red, Green, Blue) colour space format, while OpenCV operates by assuming the BGR (Blue, Green, Red) colour space format. The image arrays must thus be converted to account for this, using the function cvtColor(). The output of this function will be an image array that is saved in the BGR colour space format.

## 4.2 Camera Calibration

In this section, the four steps necessary to calibrate a stereoscopic camera system will be discussed and explained. For this project, we will focus on calibrating the camera system using a planar calibration target. Various types of calibration targets can be used, such as chessboard patterns, circle grids, ArUco markers, and Charuco targets. The project will focus on using a chessboard pattern to calibrate the camera system and will follow the flow as indicated in Figure 9.

Figure 9: Stereo Camera Calibration Flow.

### 4.2.1 Convert Images to Grayscale

It is a general practice to convert images to grayscale when calibrating cameras. This is done to simplify corner detection, reduce computational complexity and improve the robustness to colour and lighting variations. The chessboard corner detection algorithm relies on intensity gradients captured in grayscale, making colour irrelevant in this situation. This conversion is done for each image using the function cvtColor(), which takes the captured image in the BGR colour space and converts it into the grayscale colour space, as seen in Figure 10.

### 4.2.2 Chessboard Corner Detection

The inner corners of the chessboard pattern calibration target will be used to calibrate the camera system. To locate them, OpenCV provides a function called findChessboardCorners(). The input parameters of this function include an image, the pattern size of the calibration target, and various operational flags to modify the function's behaviour. The function then outputs an array containing the detected corners in a specific order (row by row, from left to right within each row).

The image used by the function to locate the corners must be an 8-bit image (grey or colour). The pattern size of the calibration target refers to the grid size of the inner corners of the chessboard. This parameter should be provided in the format (width x height) to be correctly input into the findChessboardCorners() function. To determine the number of inner corners of a chessboard calibration target, count the points where the black squares touch each other. Figure 11 illustrates the location of the inner corners of a chessboard grid. This chessboard has a 10 x 7 grid with the inner corners marked as red dots. These dots are located at the points where the black squares touch each other. The parameter pattern size for this calibration target will be given as 9 x 6. The easiest way to determine the pattern size parameter for a chessboard calibration target is to subtract one from the width and height.

grayscale_image = cv2.cvtColor(image, cv2.COLOR_BGR2GRAY)

Figure 10: OpenCV Function Implemented for Grayscale Conversion.

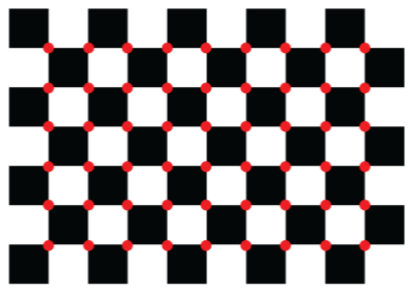
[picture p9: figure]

Figure 11: Location of Inner Corners of the Chessboard Target.

Source: “3nYBxKgnpcGoxWARhUYlDSCyy”, 2025

The final parameter that must be specified is the flags, which indicate the behaviour of the function. The names of the flags and their effects on behaviour are provided in Table 2.

Table 2: Flags Provided by the Chessboard Corner Detection Function.
Flag | Behaviour Change
CALIB_CB_PLAIN | The image is taken as is, and all other flags are ignored.
CALIB_CB_FAST_CHECK | Run a fast check to determine whether chessboard corners are found.
CALIB_CB_NORMALIZE_IMAGE | Normalise the image gamma before applying thresholding.
CALIB_CB_ADAPTIVE_THRESH | Utilise adaptive thresholding to convert the image to black and white.
CALIB_CB_FILTER_QUADS | Use additional criteria to sort out false quads extracted at the contour retrieval stage.

The flags are an essential step to ensure that corner detection is reliable. The CALIB_CB_PLAIN parameter will not be used because it processes the image as is and does not aid in corner detection. It skips robust binarisation and dilation, reducing the function's tolerance to real-world issues. Binarisation is the process of converting a grayscale image into a binary image. Dilation is a morphological operation that closes small gaps that appear after binarisation, helping to detect small or blurred squares. The CALIB_CB_FAST_CHECK parameter will be used to prevent the function from running unnecessarily long on images that do not contain a chessboard. The CALIB_CB_ADAPTIVE_THRESH parameter will be used to assist in handling photos taken under uneven lighting conditions by implementing local thresholding. Local thresholding is a technique that computes a different threshold for each pixel based on its neighbouring pixels, making it effective for images with varying illumination.

The CALIB_CB_NORMALIZE_IMAGE parameter will be implemented to enhance the contrast in low-contrast images so that black and white squares separate better before applying binarisation. The
CALIB_CB_FILTER_QUADS parameter will be used to reduce clutter from non-board rectangles visible in the image, which speeds up neighbour linking by filtering candidates to those that look square-like.

After the initial corners have been detected, the cornerSubPix() function will be used to refine them to sub-pixel accuracy. This is a crucial step for the high-accuracy task of camera calibration. The exact corner position must be known more precisely than whole pixels. This is achieved by iteratively adjusting each corner’s position to ensure the measurements are not limited to integer-level accuracy.

The function starts by taking a grayscale image and an initial set of corner coordinates as inputs. The search window is defined as a square window of size (2 × winSize + 1) × (2 × winSize + 1). This search window is centred on a corner q, as seen in Figure 12. Within the window, the image intensity gradient (DIpi) is computed at each pixel (pi
) (“OpenCV: Feature Detection”, n.d.). These gradients are used to relate changes in intensity to subpixel shifts in corner position.

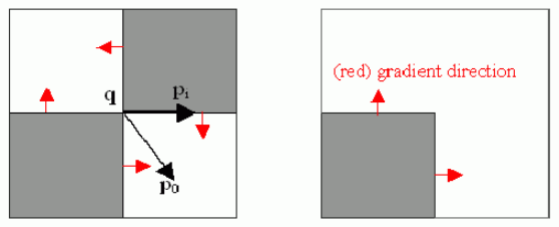
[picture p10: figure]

To locate the exact corner, each displacement vector (q − pi ) from the true corner
(q) to points (pi
) within the window should be orthogonal to the local gradient at pi
. This means that the algorithm aims to satisfy the condition where the displacement vector (q − pi

) is orthogonal to the image intensity gradient (DIpi), resulting in zero. This relationship is illustrated in Equation 4.1, where the orthogonality error (εi

) for a pixel piwithin the local window is represented. The algorithm utilises a least-squares method, aiming to minimise the orthogonality error.

εi = DIpi

T ∙ (q − pi
) ≈ 0 | (4.1)

The updated corner position q is obtained by solving Equation 4.1, yielding a new sub-pixel estimate of the corner within the search window. The algorithm sets the new centre of the neighbouring window to q and continues iterating until it stays within the set threshold defined in the criteria input parameter. This project uses two parameters under the criteria input parameter. These parameters determine the epsilon or maximum iteration values that the algorithm will follow when deciding when to terminate. The epsilon value is set to 0.001, meaning the process will stop when the centre point q moves by no more than 0.001 pixels. This helps to offset the downsides of using budget components and further the aim to achieve the best accuracy possible. A maximum of 50 iterations is set to prevent the algorithm from looping indefinitely if the epsilon value is not reached. After the algorithm has finished refining the corner locations, the camera calibration can be implemented.

Figure 12: Chessboard Corner Refinement Implementation on Corner.
Source: “cornerSubPix”, 2025

### 4.2.3 Monocular Camera Calibration

The next step in the camera calibration process is to determine the intrinsic, distortion, and per-view extrinsic parameters of each camera. This ensures that each camera’s internal optical properties are accurately interpreted and accounted for before proceeding to stereo camera calibration. OpenCV provides the necessary functions to complete monocular camera calibration. The primary function for this purpose is called calibrateCamera() and requires 12 input parameters. This primary function encapsulates the entire multi-stage calibration process and consists of multiple smaller functions used to complete the process.

The primary function calls the calibrateCameraInternal() function, which acts as the core for executing Zhang’s calibration method. Zhang’s method requires a simple, planar pattern to be observed from multiple different orientations. The architecture of the calibrateCameraInternal() function follows a sturdy two-stage process. First, the function conducts an initial parameter estimation. Then, it performs non-linear refinement to simultaneously adjust all parameters by minimising the overall error metric.

The initial parameter estimation has two possible avenues: either using the user-provided guessed intrinsic parameters or a linear solution derived from a homography. This project will not supply an initial guess for the intrinsic parameters and, therefore, will implement the second approach. It is assumed that the camera rig is planar because it is mounted on a levelled aluminium extrusion, which allows the closed-form initialiser used during the linear solution.

There is, however, a significant consideration to keep in mind when working with the Raspberry Pi Camera Module V3. Every time the camera uses autofocus, the intrinsic parameters must be recalculated. This is due to the physical changes in the camera’s internal geometry when autofocus is applied. The camera module physically moves the lens elements within the lens barrel to achieve focus, which changes the focal length, shifts the principal point, and alters the distortion coefficients. To combat this, the camera system will follow the steps seen in Figure 13, locking the lens in position before starting the calibration process.

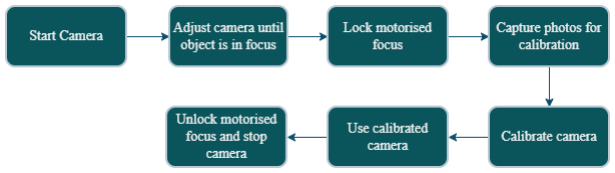
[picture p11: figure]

Figure 13: Process of Handling Autofocus during Image Capturing.

After the function has calculated the focal lengths, they are saved in the camera matrix, ready for further refinement. The next step is to initialise the extrinsic
parameter | estimation | using | the | function
findExtrinsicCameraParams2(). As with the intrinsic parameters, no initial guess for the extrinsic parameters is provided; instead, they are estimated from a homography matrix.

So far, the intrinsic and extrinsic parameters have been initialised and estimated. The final step in monocular camera calibration is to optimise these estimated parameters using a Levene-Marquardt (LM) optimisation loop to simultaneously refine both the intrinsic and per-view extrinsic parameters. The LM solver computes the per-point reprojection errors (also known as residuals) at each iteration. It aims to minimise the sum of squared residuals across all points and images. The solver compares the total squared reprojection error and the change in parameters to determine the next step. The decision is based on error improvement: if the new error is lower than the previous one, the parameter change is accepted and the damping factor is decreased. Decreasing the damping factor allows the solver to take larger, bolder steps. Conversely, if the new error exceeds the previous error, the parameter change is rejected, and the damping factor is increased to prevent larger steps. The solver terminates when either the parameter change or the error reduction becomes very small, indicating convergence. Alternatively, the process stops when the maximum number of iterations is reached.

### 4.2.4 Stereo Camera Calibration

The next step in calibrating the stereo camera system is to implement the function stereoCalibrate() to obtain the extrinsic camera parameters. The intrinsic parameters will be fixed because they have already been optimised during monocular camera calibration. This will be achieved by passing the flag CALIB_FIX_INTRINSIC to the function, indicating that it should only optimise the relative pose between the cameras. The function implements a small Levenberg-Marquardt (LM) solver to find a consistent pose for each image, also accounting for distortion. Immediately after, the code calls the function findExtrinsicCameraParams2() to refine the pose. It is implemented in the same way as mentioned in the monocular camera calibration section.

The function provides six componentsthat are the relative stereo pose parameters between the two cameras. The first three components are the rotation from camera 1 to camera 2 in radians. The other three components are the translation from camera 1 to camera 2 in millimetres. These components are the parameters computed per image. To ensure robustness, the median of each component is used as the initial global parameter guess before the stereo LM refinement. The parameter refinement is implemented in the same way as described in the monocular camera calibration section. The stereoCalibrate() function concludes by returning the overall RMS reprojection error across both cameras.

## 4.3 Rectify Stereo Image Pair

Stereo rectification is a geometric transformation applied to a pair of stereo images. This transformation adjusts both images so they appear as if taken by two cameras with a perfectly parallel setup. The primary aim of this process is to ensure that the epipolar lines in both images become horizontal and parallel. Rectifying stereo image pairs makes it easier to find corresponding points between the two images, which is essential for 3D reconstruction. The primary purpose is to convert the process of searching for matching points from a 2D problem into a 1D problem. This is achieved by searching along the epipolar lines to identify the corresponding points.

OpenCV provides a function, called stereoRectify(), that calculates the transformation matrices needed to align a pair of stereo images. This function takes the calculated intrinsic camera matrices and distortion parameters for both cameras, along with the rotation and translation matrices computed in the previous sections. The outputs generated from this function are two 3x3 rotation matrices for the left and right cameras. These rotation matrices define the exact rotation needed for each camera to make them parallel. The function also outputs two 3x4 matrices that represent the new projection matrices for the rectified cameras. These matrices project the 3D points onto the new, rectified image planes. The last output of the stereoRectify() function is a 4x4 matrix, called the disparity-to-depth mapping matrix. This is an essential component used during 3D reconstruction to convert a 2D pixel's disparity value into a 3D coordinate in real-world space.

The five output parameters are passed to the OpenCV function called initUndistortRectifyMap() to precompute two efficient lookup maps for each camera. These lookup maps are created for the x- and y-coordinates. This step is performed to ensure that the computationally expensive task of calculating the complex transformations needed to rectify and undistort an image is only executed once. If these maps were not created, complex transformations would need to be done for every image being rectified. To rectify an image, the OpenCV function remap() is called by passing the original image and the two lookup maps of the camera on which the image was captured. The function creates a new image by copying pixels from the original, distorted photo, using the corrected values obtained from the lookup maps.

It starts by examining a pixel coordinate that needs to be filled in the new image, for example, (10, 5). To determine the new pixel’s x-coordinate, it looks at the lookup map for the x-coordinates at the position (10, 5). This provides a value for the new x-coordinate of that pixel, for example, 12.7. The same is done to find the y-coordinate, but with the lookup map for the y-coordinate. If the value found is 8.2, the function now knows that to fill the new pixel at coordinate (10, 5), it must find the colour from the original, distorted image at the coordinate (12.7, 8.2). The non-integer coordinate leads to a new problem. There is no pixel at the coordinate (12.7, 8.2) in the original image. To account for this, the flag INTER_LINEAR is passed to the remap() function. This indicates that bilinear interpolation will be performed to determine the colour of the new pixel. The function repeats the task of looking up and assigning the new colour until all pixels in the new image are filled. The process of rectifying an image pair is illustrated in Figure 14.

## 4.4 Illustration of Disparity Map

The rectified images will be used to compute a disparity map of the scene observed by the cameras. This disparity map provides a visual representation of the disparity in various areas within the image scene. This creates a map that can be used to see the relative distance of objects from the camera system. This is done by implementing a Block Matching (BM) algorithm. This advanced stereo matching algorithm computes the disparity by finding the corresponding points between the left and right rectified images. For each pixel in the left image, the BM algorithm searches for the matching pixel in the right image along the same epipolar line. The displacement between the two matching points is the disparity, and is inversely proportional to the depth. OpenCV provides a total of four BM algorithms. The four methods, from fastest to slowest, are 3WAY, HH4, SGBM and HH. To ensure that the system employs a balance of accuracy and time efficiency, the Semi-Global Block Matching (SGBM) method will be implemented

OpenCV provides a function called StereoSGBM_create() to create the SGBM matcher, which can compute the disparity between an image pair. The StereoSGBM_create() function accepts the parameters used to develop the BM algorithm and, in turn, creates an object that can be triggered to start the SGBM algorithm. The parameter minDisparity has a value of 0, indicating that the algorithm will begin its search by assuming pixels can be at the same horizontal position. The parameter numDisparity indicates the total range of disparity values that the algorithm will search for. This parameter must be divisible by 16 to return an integer value in future calculations. The parameter was set to 512, allowing the algorithm to calculate the disparity of objects close to the camera system, albeit at the expense of increased computational time. The blockSize parameter is the side length of the pixel window used for matching. The algorithm compares a 5x5 block of pixels from the left image to the right, not just a single

Figure 14: Image Rectification Process.

pixel. This ensures the robustness of the algorithm in finding matching areas and requires that the number be odd. The algorithm has two penalty parameters, P1 and P2. These parameters help control the smoothness of the final disparity, especially when P2 > P1. P1 is the penalty for small disparity changes between adjacent pixels, and P2 is the penalty for significant, sudden disparity changes. The values for P1 and P2 were found iteratively and are 8 and 24, respectively. The final two parameters are the uniquenessRatio and mode. The uniquenessRatio ensures that the match is only accepted if it is unique, determined by the percentage improvement of the best match over the second-best match. This project will utilise a 5% improvement requirement after iteratively determining the best value. The mode parameter will be STEREO_SGBM_MODE_SGBM, which indicates that the SGBM algorithm will be implemented.

The disparity will be computed by triggering the SGBM algorithm, passing the grayscale image pair and scaling the output to its true pixel value by dividing it by 16 to reverse the internal multiplication done by the OpenCV function. The final step before the disparity map can be created is to normalise the disparity data into a standard 8-bit grayscale image. This is done using the OpenCV function normalize(), which accepts the computed disparity and normalises it between its minimum and maximum values. This is done by passing the parameter NORM_MINMAX and indicating the minimum and maximum values of the output image as 0 and 255, respectively.

## 4.5 Single Image Camera Calibration

This section will walk you through the implementation of a stereo camera calibration technique using a single 3D calibration plate. Inspiration was taken from the LaVision camera system and its implementation of stereo camera calibration using only a single image pair. The LaVision software DaVis automatically detects the dots on the 3D calibration plate and uses them to calibrate the system. The conventional planar calibration targets, like the chessboard used in the previous section, require taking several views to combat the limitations of implementing Zhang’s method(Zhang & Research, 2000). According to Zhang’s calibration method, the planar calibration target must be viewed from multiple orientations and distances to calculate the intrinsic parameters of a camera. This means that single-view camera calibration will not be possible when using a planar calibration, due to it not being viewed from multiple angles. Using a 3D calibration target provides more information for calibration. The single image camera calibration process discussed in this section will replace the camera calibration process that were introduced in Section 4.2 as illustrated in Figure 15.

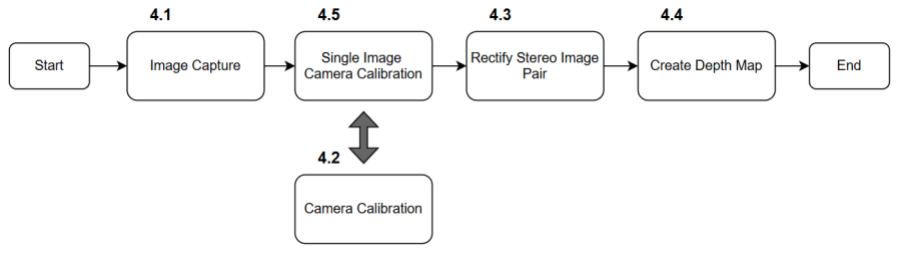
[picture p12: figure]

### 4.5.1 Preprocess Images

The captured images require preprocessing to extract all the necessary features while remaining robust in many situations. All preprocessing steps are grouped into a custom function called preprocess_image(), which accepts the captured images. The images captured must once again be converted into the grayscale colour space. This is done because thresholding and circle detection operate on grayscale images, instead of colour images. Like in the previous methods, the conversion will be done using the cvt.Color() function. The converted images are then further processed by applying the function GaussianBlur()to smooth the image and prevent random bright pixels from being falsely identified as dots. Multiple other blurring methods are available from the OpenCV library. These methods can be seen in Table 3 with a short explanation on how they work and their downsides.

Table 3: Blurring Methods Provided by the OpenCV Library.

Method | How it works | Downside
Averaging Blur | Replaces each pixel with the average value of all pixels in a square area. | Tends to create box-like artefacts and is not good at preserving edges.
Median Blur | Replaces each pixel value with the median value of its neighbouring pixels. | Significantly slower than a Gaussian blur, it creates regions of uniform intensities with block sharp gradient changes, which is not ideal for detecting circles. It can distort the shapes, leading to false classifications.
Bilateral Filter | Replaces each pixel with an average value of nearby pixels that are also similar in brightness. | It is significantly slower than the other methods, requiring increased computational cost. Its edge-preserving feature prevents the smooth gradient needed by the circle detection function.

Figure 15: Single-Image Calibration Places within the Existing Flow.

After testing the different blur methods and comparing their effect on the circle detection function, it was found that the Gaussian blur is the best option for this project. The averaging and median blur methods do not preserve the circle's edges when passed to the circle detection function, as discussed in Section 4.5.2. The bilateral filter method does not work with the circle detection function, as mentioned in Table 3. The Gaussian blur accepts two parameters: the kernel size and a sigma value. The kernel size controls how many pixels are averaged together, controlling the spread of the blur. After testing, the kernel size was determined to be 5x5, meaning 25 pixels will be averaged together. The sigma value was set to 0, allowing the function to automatically calculate the optimal sigma value for the given kernel size.

The next step in preprocessing the image for circle detection is to apply thresholding to the blurred image. This is done to convert the blurred grayscale image into a pure black and white image. It simplifies the image by removing all ambiguous grey values by forcing all pixels to be either black or white. This is accomplished by determining whether a given pixel is brighter or darker than a given threshold. When the pixel is brighter than the threshold, it is set to a value of 255, indicating that it is white. Conversely, if it is darker than the threshold, it is set to a value of 0, indicating that it is black. A clean, high-contrast image is created where the circles are clearly distinguished from the background. To ensure the circle detection is robust against varying lighting conditions, the adaptive thresholding method is implemented. Adaptive thresholding is chosen above other methods, like global thresholding and Otsu’s binarisation, due to its ability to apply thresholding to multiple smaller local areas. This is better because it does not rely on one brightness value to work for the entire image. Adaptive thresholding is a more robust solution and can work even if the image has shadows or bright glares on it.

To implement this feature, the function adaptiveThreshold() is called and receives the blurred images as input. The function also receives additional parameters needed to optimise the function for this use case. Max value indicates the value that will be assigned to pixels greater than the threshold. The local threshold of an area is calculated using a Gaussian-weighted average of the neighbours, indicated by passing the flag ADAPTIVE_THRESH_GAUSSIAN_C. The thresholding rule is set to binary using the flag THRESH_BINARY, indicating that values less than or equal to the threshold will be set to 0 (black). The neighbourhood size that will be used to calculate the local threshold is set to 5, indicating a 5x5 pixel area. This was determined through testing with values ranging from 3 to 101. A small value, for example, 3, is susceptible to noise and could lead to an unstable threshold. Larger values, like 101, can fail to adapt to lightning changes and act more like a global threshold.

The last part in preprocessing is to clean the images by implementing morphological operations. These image preprocessing techniques modify the shape and structure of objects within an image. This is done by sliding a kernel across the image and deciding whether the pixel at its centre should be changed. The decision is based on a set rule, either erosion or dilation. The rule of erosion is to set a pixel white only if all pixels under the kernel are also white. Thus, the centre pixel is eroded and turned black even if only one pixel in the kernel is black. The rule of dilation is the inverse of erosion, meaning that the centre pixel is set to white if at least one pixel under the kernel is white. The function used to achieve these processes is morphologyEx(), provided by the OpenCV library. This function takes the image after adaptive thresholding has been applied and, depending on the flag, applies either erosion or dilation. The two flags that indicate what operation is applied are MORPH_CLOSE and MORPH_OPEN.

In this project, the code first applies the function morphologyEx() with the MORPH_OPEN flag. This is done to clean the background by removing small, isolated white specks from the black areas. These white specks are due to any remaining noise and are removed by erosion. After erosion, the function performs dilation to restore the circles to their original size without the presence of white specks. The MORPH_OPEN flag indicates erosion followed by dilation.

The next step is to apply the morphologyEx()function again, but this time passing the MORPH_CLOSE flag to indicate that dilation will be done, followed by erosion. This step is necessary to fill in any black holes that might appear inside the circles.

### 4.5.2 Circle Identifier

Circle identification will be handled in a custom-made function called detect_dots_hough(). This function identifies the circles of the calibration plate and verifies that all detected circles have a white centre. Figure 16 indicates the flow of the function detect_dots_hough().

The detect_dots_hough() function implements the OpenCV function called HoughCircles() to identify the circles. This function accepts seven parameters to identify the circles, most of which require fine-tuning to detect dots at various distances. To simplify the implementation of the circle finding in this project, the circle identification will be conducted on the same 3D calibration plate at a constant distance of 400 mm. This ensures that the circles of the calibration

Figure 16: Flow of Circle Identification Function.

plate will remain approximately the same size, regardless of the plate's orientation. Fine-tuning of the parameters was done using a custom-written Python script that can be found at the following link (https://github.com/Franco-skripsie/Development-of-a-Stereoscopic-Camera-System-for-3D-Deformation-Analysis) to the GitHub page. This script took a preprocessed image and provided a live GUI to tune the parameters until all circles were detected. The parameters are provided in Table 4, along with their explanations and fine-tuned values that were passed to the HoughCircles() function.

Table 4: Parameters Passed to HoughCircles Function.

Parameter | Explanation | Value
dp | Inverse ratio of accumulator resolution to image resolution. | 1
minDist | Minimum distance between the centres of the detected dots. | 25
param1 | Upper threshold for the internal Canny edge detector. | 50
param2 | Accumulator threshold for the centre detection. | 15
minRadius | Minimum circle radius to detect. | 9
maxRadius | Maximum circle radius to detect. | 17
method | The detection method used. | HOUGH_GRADIENT

The second part of the detect_dots_hough()function is to verify that the detected circles are from the 3D calibration plate and to filter out false positives. This is done by calling the custom function is_center_white(), which verifies that the detected circles have a white centre as expected. It takes a coordinate of the detected circle’s centre and verifies whether it is brighter than the threshold. When the circle’s centre is greater than the selected threshold of 180, the function will return True, indicating that this is a circle. When false is returned, that circle is discarded from the detected circles. The is_center_white()function will iterate through all the detected circles in the image until all the false positives are cleared. When this is completed, the function detect_dots_hough()will return a variable that contains a list of all the coordinates of the circle centres that have been confirmed.

### 4.5.3 Assigning Dots into Columns

The next step in implementing the custom calibration method is to sort the detected circles into columns based on their coordinates. The calibration plate is shown in Figure 17, illustrating the multiple layers that provide its 3D characteristics.

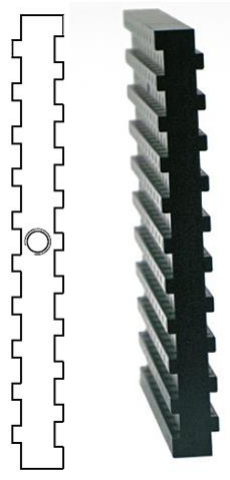
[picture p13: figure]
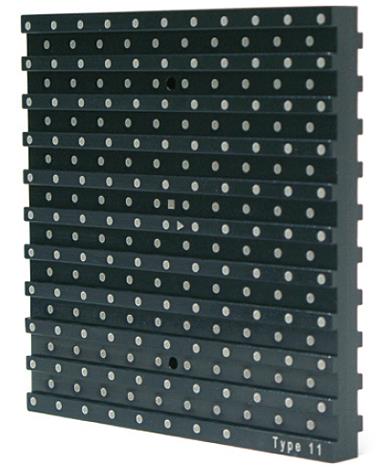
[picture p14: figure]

The circles are arranged into two grids, one being elevated above the other. To ensure that the columns are correctly assigned, the calibration plate will always be captured in one specific orientation. This will ensure that the system is more robust when defining columns and does not rely on detection markers to know its orientation. The calibration plate will always be captured in the same approximate orientation, with the white triangle located North-East of the centre square. In this orientation, the calibration plate will have circles oriented into 23 columns and 23 rows. Since this will remain constant for the orientation in which the plate is captured, the code will assign dots accordingly.

To assign the circles to the correct columns, a custom function called cluster_into_columns() was created, seen in Figure 18. This function works by isolating the x-coordinates of the circles’ centres and then using K-means clustering to create exactly 23 groups based on these coordinates. The groups created during the K-means clustering are in an arbitrary order and must be ordered into the correct column order before they can be assigned to one of the two grids. The function ends by saving the circle's full coordinates into the correct column list based on the sorted mapping.

To isolate the x-coordinates, the detected circle centres are taken, and only the x-coordinates are saved into a NumPy array. K-means clustering is achieved by first configuring the KMeans()function. This tells the algorithm to find exactly 23 clusters by passing the parameter n_clusters=23. To ensure that the clustering is more accurate, the entire algorithm will be run 10 separate times with different random starting points. This is done by passing the n_init=10 parameter to the function, allowing it to pick the best one out of the ten runs automatically. After the function is configured, the fit_predict method is

Figure 17: LaVision’s 3D Calibration Plate.

Figure 18: Column Clustering Function Flow.

Source: “c6e347fc-5772-4522-a501-af7b22bc4204”, 2025 called, and the x-coordinates array is passed into it. This method runs the algorithm in two steps: first, it “fits” the model by determining the 23 best x-positions for the column centres from the data. Second, it “predicts” by going back through every circle and assigning it the ID label of the cluster it is closest to. The final result is stored in an array which contains the cluster ID for every circle.

The K-means algorithm identifies the 23 groups of circles but does not determine which groups correspond to which columns. To address this, the function np.argsort() is used. It will sort the list of group IDs based on the x-coordinates, from smallest to largest. An ID-to-column dictionary is created to map the ID of the 23 groups to the corresponding column of the calibration plate. The final step in the cluster_into_columns() function is to group the circles into their closest column and refine where necessary. This is achieved by looping through every circle and adding the full circle centre’s coordinates to its column list. The average x-coordinate of the circles in a column is calculated and passed to the custom-created function called refine_column_assignment(). After the columns are finalised, the code loops through each column and sorts the dots within it based on their y-coordinates, in a top-down manner.

### 4.5.4 Sort Columns into Two Grids

The 3D calibration plate can be divided into two grids to utilise its 3D characteristics. These two grids have a depth separation of 1 mm between them, as seen in Figure 17. This depth separation will be used to assist the single-image calibration process. Grid A is identified by the circles on the plane furthest from the camera system and corresponds to all the odd-numbered columns. Grid B contains all the even-numbered columns and is located closest to the camera system, with a 1 mm offset from Grid A.

The sorting of the columns is achieved by utilising the custom-created function assign_grids_and_sort(). This function iterates through all 23 columns and checks if the column number is odd or even. If it is odd, all the circles' coordinates in that column are saved into a list created for Grid A. If the column number is even, the coordinates are saved into the list for Grid B. Once it has iterated through the columns, the lists are converted into arrays and returned as outputs. The columns' internal order is kept consistent; therefore, all circles are in the correct locations.

### 4.5.5 Calibrating Cameras

The Zhang's calibration method requires that the calibration target be viewed from multiple orientations. Because the suggested single-image calibration method will not capture the target in various orientations, the intrinsic parameters will be guessed. The flag CALIB_USE_INTRINSIC_GUESS will be passed to the calibrateCamera() function. The camera calibration functions as discussed in Sections 4.2.3 and 4.2.4, with the only difference being that the two grids will be used as if they were from two separate images. The number of circles in each column will be made equal by trimming the outer layer of circles. The stereoCalibrate() function will be implemented in the same way with no changes needed. The function will return the same value types as when running the chessboard calibration method.

## 4.6 Chapter Summary

This chapter discussed the design for the software created to ensure the operation of the stereo camera system. It explained how the images will be captured, preprocessed and used to calibrate the cameras. The requirements needed to create a disparity map were explained and also how the single image calibration method are created. The next chapter will walk through the processes of implementing the code and the analysis of the results.

## 5 Result and Analysis

This section presents the results and analysis obtained from conducting tests and experiments using the camera system. Attention was given to the safety of all people and equipment during the testing phase. Refer to Appendix 5.7C.2 to find more information on the safety aspects considered and the safety report compiled for working in the laboratory. All testing was conducted in a safe and secure environment.

A mouse, keyboard and monitor were connected to the RPi 5 to control and navigate the implemented code. The camera system could have also been controlled from another device using the Raspberry Pi Connect service. This is a secure remote access service provided by Raspberry Pi to control most Raspberry Pi models from a web browser.
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

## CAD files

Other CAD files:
Base to Mounting Rail Connector/Base_Mounting_Rail_Connector.ipt
Camera Enclosure/Camera_Backplate.ipt
Camera Enclosure/Camera_Enclosure_Left.ipt
Camera Enclosure/Camera_Enclosure_Right.ipt
RPi5 Enclosure/RPi5_Enclosure_Bottom.ipt
RPi5 Enclosure/RPi5_Enclosure_Top.ipt

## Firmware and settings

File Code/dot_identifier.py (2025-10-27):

#!/usr/bin/env python3
"""
Dot Identifier for Custom 3D Calibration Plate

This script processes stereo camera calibration images containing an asymmetric circle grid
with 264 white dots on a black background. The calibration plate has:
- 23 columns total
- Grid A: Odd columns (1,3,5,7,9,11,13,15,17,19,21,23) with 12 rows each, except column 23 which has no row 2 dot (143 dots)
- Grid B: Even columns (2,4,6,8,10,12,14,16,18,20,22) with 11 rows each (121 dots)
- Dot spacing: 5mm within same grid
- Dot diameter: 1.2mm
- Grid A and B separated by 1mm depth

The script detects all dots, clusters them into columns, assigns them to grids,
and outputs ordered point arrays for stereo calibration.

"""

import cv2
import numpy as np
import argparse
import os
import sys
import pandas as pd
from sklearn.cluster import KMeans
import matplotlib.pyplot as plt
from typing import Tuple, List, Optional


def load_image(image_path: str) -> Optional[np.ndarray]:
    """
    Load an image from the specified path.
    
    Args:
        image_path (str): Path to the image file
        
    Returns:
        np.ndarray: Loaded image or None if failed
    """
    if not os.path.exists(image_path):
        print(f"Error: Image file '{image_path}' not found.")
        return None
    
    image = cv2.imread(image_path)
    if image is None:
        print(f"Error: Could not load image '{image_path}'.")
        return None
    
    print(f"Loaded image: {image_path} with shape {image.shape}")
    return image


def preprocess_image(image: np.ndarray, output_prefix: str = None) -> np.ndarray:
    """
    Preprocess the image to isolate white dots on black background.
    
    Args:
        image (np.ndarray): Input BGR image
        output_prefix (str): Optional prefix for saving intermediate images
        
    Returns:
        np.ndarray: Binary image with white dots
    """
    # Convert to grayscale
    gray = cv2.cvtColor(image, cv2.COLOR_BGR2GRAY)
    if output_prefix:
        cv2.imwrite(f"{output_prefix}_step1_grayscale.png", gray)
        print(f"Saved: {output_prefix}_step1_grayscale.png")
    
    # Apply Gaussian blur to reduce noise
    blurred = cv2.GaussianBlur(gray, (5, 5), 0)
    if output_prefix:
        cv2.imwrite(f"{output_prefix}_step2_blurred.png", blurred)
        print(f"Saved: {output_prefix}_step2_blurred.png")
    
    # Apply threshold to get binary image (white dots on black background)
    # Using adaptive threshold to handle varying lighting conditions
    binary = cv2.adaptiveThreshold(
        blurred, 255, cv2.ADAPTIVE_THRESH_GAUSSIAN_C, cv2.THRESH_BINARY, 5, 2
    )
    if output_prefix:
        cv2.imwrite(f"{output_prefix}_step3_binary.png", binary)
        print(f"Saved: {output_prefix}_step3_binary.png")
    
    # Morphological operations to clean up the image
    kernel = cv2.getStructuringElement(cv2.MORPH_ELLIPSE, (3, 3))
    binary_open = cv2.morphologyEx(binary, cv2.MORPH_OPEN, kernel)
    if output_prefix:
        cv2.imwrite(f"{output_prefix}_step4_morphology_open.png", binary_open)
        print(f"Saved: {output_prefix}_step4_morphology_open.png")
    
    binary = cv2.morphologyEx(binary_open, cv2.MORPH_CLOSE, kernel)
    if output_prefix:
        cv2.imwrite(f"{output_prefix}_step5_morphology_close.png", binary)
        print(f"Saved: {output_prefix}_step5_morphology_close.png")
    
    return binary


def is_center_white(image: np.ndarray, x: int, y: int, threshold: int = 180) -> bool:
    """
    Check if the center pixel of a detected circle is white (bright).
    
    Args:
        image: Original image (grayscale or color)
        x, y: Center coordinates
        threshold: Minimum brightness value to consider white
        
    Returns:
        bool: True if center pixel is white enough
    """
    if len(image.shape) == 3:
        # Convert to grayscale if color image
        gray = cv2.cvtColor(image, cv2.COLOR_BGR2GRAY)
    else:
        gray = image
    
    h, w = gray.shape
    if 0 <= x < w and 0 <= y < h:
        return gray[y, x] >= threshold
    return False


def detect_dots_hough(binary_image: np.ndarray, original_image: np.ndarray = None,
                      min_dist: int = 25, param1: int = 50, param2: int = 15, 
                      min_radius: int = 9, max_radius: int = 17, white_threshold: int = 180) -> List[Tuple[float, float]]:
    """
    Detect dots using HoughCircles with white center validation.
    
    Args:
        binary_image (np.ndarray): Binary image with white dots
        original_image (np.ndarray): Original image for center validation
        white_threshold (int): Threshold for white center detection
        
    Returns:
        List[Tuple[float, float]]: List of (x, y) coordinates of dot centers
    """
    # Apply HoughCircles to detect circular dots
    circles = cv2.HoughCircles(
        binary_image,
        cv2.HOUGH_GRADIENT,
        dp=1,
        minDist=min_dist,  # Minimum distance between circle centers
        param1=param1,     # Upper threshold for edge detection
        param2=param2,     # Accumulator threshold for center detection
        minRadius=min_radius, # Minimum circle radius
        maxRadius=max_radius  # Maximum circle radius
    )
    
    dots = []
    if circles is not None:
        circles = np.round(circles[0, :]).astype("int")
        total_detected = len(circles)
        
        # Filter circles by center color if original image provided
        if original_image is not None:
            filtered_circles = []
            for x, y, r in circles:
                if is_center_white(original_image, x, y, white_threshold):
                    filtered_circles.append((x, y, r))
            
            dots = [(float(x), float(y)) for x, y, r in filtered_circles]
            print(f"HoughCircles detected {total_detected} circles, {len(dots)} with white centers (threshold: {white_threshold})")
        else:
            dots = [(float(x), float(y)) for x, y, r in circles]
            print(f"HoughCircles detected {len(dots)} dots (no center validation)")
    
    return dots


def cluster_into_columns(dots: List[Tuple[float, float]], num_columns: int = 23) -> List[List[Tuple[float, float]]]:
    """
    Cluster dots into columns based on x-position with robust gradient-based refinement.
    
    Args:
        dots (List[Tuple[float, float]]): List of dot coordinates
        num_columns (int): Expected number of columns (23)
        
    Returns:
        List[List[Tuple[float, float]]]: List of columns, each containing dots
    """
    if len(dots) == 0:
        return [[] for _ in range(num_columns)]
    
    # Extract x-coordinates for clustering
    x_coords = np.array([dot[0] for dot in dots]).reshape(-1, 1)
    
    # Use K-means clustering to group dots into columns
    kmeans = KMeans(n_clusters=num_columns, random_state=42, n_init=10)
    column_labels = kmeans.fit_predict(x_coords)
    
    # Sort cluster centers by x-position to get column order
    cluster_centers = kmeans.cluster_centers_.flatten()
    sorted_indices = np.argsort(cluster_centers)
    
    # Create mapping from cluster label to column index
    label_to_column = {old_label: new_idx for new_idx, old_label in enumerate(sorted_indices)}
    
    # Group dots by column
    initial_columns = [[] for _ in range(num_columns)]
    for i, dot in enumerate(dots):
        column_idx = label_to_column[column_labels[i]]
        initial_columns[column_idx].append(dot)
    
    # Calculate column centers and expected spacing pattern
    column_centers = []
    for column in initial_columns:
        if column:
            avg_x = np.mean([dot[0] for dot in column])
            column_centers.append(avg_x)
        else:
            column_centers.append(0)  # Will be interpolated
    
    # Robust column assignment using gradient analysis
    refined_columns = refine_column_assignment(dots, initial_columns, column_centers)
    
    # Sort dots within each column by y-coordinate (top to bottom)
    for column in refined_columns:
        column.sort(key=lambda dot: dot[1])
    
    print(f"Clustered dots into {num_columns} columns:")
    for i, column in enumerate(refined_columns):
        print(f"  Column {i+1}: {len(column)} dots")
    
    return refined_columns


def refine_column_assignment(dots: List[Tuple[float, float]], 
                           initial_columns: List[List[Tuple[float, float]]], 
                           column_centers: List[float]) -> List[List[Tuple[float, float]]]:
    """
    Refine column assignment using gradient analysis and expected spacing patterns.
    
    Args:
        dots: Original dot list
        initial_columns: Initial K-means clustering result
        column_centers: X-coordinates of column centers
        
    Returns:
        Refined column assignments
    """
    # Calculate average spacing between columns
    valid_centers = [c for c in column_centers if c > 0]
    if len(valid_centers) < 2:
        return initial_columns
    
    spacings = []
    for i in range(1, len(valid_centers)):
        spacings.append(valid_centers[i] - valid_centers[i-1])
    
    avg_spacing = np.median(spacings)
    spacing_tolerance = avg_spacing * 0.4  # 40% tolerance for spacing variation
    
    print(f"Average column spacing: {avg_spacing:.1f} pixels")
    print(f"Spacing tolerance: {spacing_tolerance:.1f} pixels")
    
    # Identify problematic assignments based on expected patterns
    refined_columns = [[] for _ in range(len(initial_columns))]
    
    # For each dot, find the best column assignment
    for dot in dots:
        x, y = dot
        best_column = 0
        min_distance = float('inf')
        
        # Find closest column center
        for col_idx, center_x in enumerate(column_centers):
            if center_x > 0:  # Valid center
                distance = abs(x - center_x)
                if distance < min_distance:
                    min_distance = distance
                    best_column = col_idx
        
        # Verify assignment makes sense based on spacing pattern
        expected_center = column_centers[best_column]
        if expected_center > 0 and min_distance < spacing_tolerance:
            refined_columns[best_column].append(dot)
        else:
            # Fall back to original assignment if refinement fails
            original_col = find_original_column(dot, initial_columns)
            if original_col is not None:
                refined_columns[original_col].append(dot)
    
    # Post-process: redistribute dots from over-populated to under-populated columns
    refined_columns = redistribute_boundary_dots(refined_columns, column_centers, avg_spacing)
    
    return refined_columns


def find_original_column(target_dot: Tuple[float, float], 
                        initial_columns: List[List[Tuple[float, float]]]) -> int:
    """Find which column a dot was originally assigned to."""
    for col_idx, column in enumerate(initial_columns):
        if target_dot in column:
            return col_idx
    return 0  # Default to first column


def redistribute_boundary_dots(columns: List[List[Tuple[float, float]]], 
                              column_centers: List[float], 
                              avg_spacing: float) -> List[List[Tuple[float, float]]]:
    """
    Redistribute dots that might be on column boundaries to improve balance.
    
    Args:
        columns: Current column assignments
        column_centers: X-coordinates of column centers  
        avg_spacing: Average spacing between columns
        
    Returns:
        Redistributed column assignments
    """
    # Expected dots per column based on grid pattern
    expected_counts = []
    for i in range(len(columns)):
        col_num = i + 1
        if col_num % 2 == 1:  # Odd columns (Grid A)
            if col_num == 23:  # Special case: column 23 missing row 2
                expected_counts.append(11)
            else:
                expected_counts.append(12)
        else:  # Even columns (Grid B)
            expected_counts.append(11)
    
    print("Expected vs Actual dot counts:")
    for i, (expected, actual) in enumerate(zip(expected_counts, [len(col) for col in columns])):
        if expected != actual:
            print(f"  Column {i+1}: Expected {expected}, Got {actual} ({'over' if actual > expected else 'under'} by {abs(actual - expected)})")
    
    # Apply targeted redistribution for problematic adjacent pairs
    # Dynamically find problem pairs instead of hard-coding them
    problem_pairs = []
    
    for i in range(len(columns) - 1):
        current_count = len(columns[i])
        next_count = len(columns[i + 1])
        current_expected = expected_counts[i]
        next_expected = expected_counts[i + 1]
        
        # Check if redistribution would help both columns
        if (current_count > current_expected and next_count < next_expected):
            problem_pairs.append((i, i + 1))
        elif (current_count < current_expected and next_count > next_expected):
            problem_pairs.append((i + 1, i))  # Reverse order
    
    print(f"Found {len(problem_pairs)} problematic column pairs for redistribution")
    
    for from_idx, to_idx in problem_pairs:
        if from_idx < len(columns) and to_idx < len(columns):
            from_count = len(columns[from_idx])
            to_count = len(columns[to_idx])
            from_expected = expected_counts[from_idx]
            to_expected = expected_counts[to_idx]
            
            print(f"Checking redistribution from column {from_idx + 1} to {to_idx + 1}")
            print(f"  From: {from_count}/{from_expected}, To: {to_count}/{to_expected}")
            
            # Check if redistribution would help both columns
            if from_count > from_expected and to_count < to_expected:
                # Find boundary dots between these columns
                boundary_dots = find_boundary_dots(columns[from_idx], columns[to_idx], 
                                                 column_centers[from_idx], column_centers[to_idx])
                
                print(f"  Found {len(boundary_dots)} boundary dot candidates")
                
                if boundary_dots:
                    # Move the best candidate
                    best_dot = boundary_dots[0]  # Closest to target column
                    columns[from_idx].remove(best_dot)
                    columns[to_idx].append(best_dot)
                    print(f"  SUCCESS: Redistributed dot {best_dot} from column {from_idx + 1} to column {to_idx + 1}")
                    
                    # Resort the target column
                    columns[to_idx].sort(key=lambda dot: dot[1])
                    
                    # Update counts for potential multiple redistributions
                    from_count -= 1
                    to_count += 1
                    
                    # Check if we can redistribute one more dot if needed
                    if from_count > from_expected and to_count < to_expected and len(boundary_dots) > 1:
                        second_dot = boundary_dots[1]
                        columns[from_idx].remove(second_dot)
                        columns[to_idx].append(second_dot)
                        print(f"  SUCCESS: Redistributed second dot {second_dot} from column {from_idx + 1} to column {to_idx + 1}")
                        columns[to_idx].sort(key=lambda dot: dot[1])
                else:
                    print(f"  No suitable boundary dots found for redistribution")
            else:
                print(f"  Redistribution not needed or wouldn't help")
    
    return columns


def find_boundary_dots(from_column: List[Tuple[float, float]], 
                      to_column: List[Tuple[float, float]],
                      from_center: float, 
                      to_center: float) -> List[Tuple[float, float]]:
    """
    Find dots in from_column that are closest to to_column center.
    
    Returns dots sorted by proximity to target column (closest first).
    """
    if not from_column:
        return []
    
    # Calculate which dots are closest to the boundary
    boundary_candidates = []
    
    # Find the midpoint between columns as boundary
    boundary_x = (from_center + to_center) / 2
    
    for dot in from_column:
        x, y = dot
        dist_to_target = abs(x - to_center)
        dist_to_boundary = abs(x - boundary_x)
        
        # Consider dots that are close to the boundary between columns
        # Use a more generous criterion for boundary detection
        if dist_to_boundary < abs(from_center - to_center) * 0.3:  # Within 30% of inter-column distance
            boundary_candidates.append((dot, dist_to_target))
    
    # If no boundary candidates, try the dots closest to target
    if not boundary_candidates:
        for dot in from_column:
            x, y = dot
            dist_to_target = abs(x - to_center)
            boundary_candidates.append((dot, dist_to_target))
    
    # Sort by distance to target column (closest first)
    boundary_candidates.sort(key=lambda x: x[1])
    
    print(f"    Boundary candidates: {len(boundary_candidates)}")
    if boundary_candidates:
        print(f"    Best candidate distance to target: {boundary_candidates[0][1]:.1f}px")
    
    return [dot for dot, _ in boundary_candidates[:2]]  # Return top 2 candidates


def assign_grids_and_sort(columns: List[List[Tuple[float, float]]]) -> Tuple[np.ndarray, np.ndarray]:
    """
    Assign columns to grids A and B, and create ordered point arrays.
    
    Grid A: Odd columns (1,3,5,7,9,11,13,15,17,19,21,23), 12 rows each, except column 23 missing row 2
    Grid B: Even columns (2,4,6,8,10,12,14,16,18,20,22), 11 rows each
    
    Args:
        columns (List[List[Tuple[float, float]]]): 23 columns of dots
        
    Returns:
        Tuple[np.ndarray, np.ndarray]: gridA_points (143, 2) and gridB_points (121, 2)
    """
    gridA_points = []
    gridB_points = []
    
    for col_idx, column in enumerate(columns):
        column_num = col_idx + 1  # 1-indexed column numbers
        
        if column_num % 2 == 1:  # Odd columns go to Grid A
            if column_num == 23:
                # Special case: column 23 has no row 2 dot (missing one dot)
                # Expected: 11 dots instead of 12
                expected_dots = 11
            else:
                expected_dots = 12
            
            if len(column) != expected_dots:
                print(f"Warning: Column {column_num} (Grid A) has {len(column)} dots, expected {expected_dots}")
            
            for dot in column:
                gridA_points.append([dot[0], dot[1]])
                
        else:  # Even columns go to Grid B
            expected_dots = 11
            
            if len(column) != expected_dots:
                print(f"Warning: Column {column_num} (Grid B) has {len(column)} dots, expected {expected_dots}")
            
            for dot in column:
                gridB_points.append([dot[0], dot[1]])
    
    # Convert to numpy arrays
    gridA_points = np.array(gridA_points, dtype=np.float32)
    gridB_points = np.array(gridB_points, dtype=np.float32)
    
    print(f"Grid A points: {gridA_points.shape}")
    print(f"Grid B points: {gridB_points.shape}")
    
    return gridA_points, gridB_points


def save_results(gridA_points: np.ndarray, gridB_points: np.ndarray, 
                 columns: List[List[Tuple[float, float]]], output_prefix: str):
    """
    Save results as numpy arrays and CSV file.
    
    Args:
        gridA_points (np.ndarray): Grid A point coordinates
        gridB_points (np.ndarray): Grid B point coordinates
        columns (List[List[Tuple[float, float]]]): Original column data
        output_prefix (str): Prefix for output files
    """
    # Save as numpy arrays
    np.save(f"{output_prefix}_gridA_points.npy", gridA_points)
    np.save(f"{output_prefix}_gridB_points.npy", gridB_points)
    print(f"Saved numpy arrays: {output_prefix}_gridA_points.npy and {output_prefix}_gridB_points.npy")
    
    # Create CSV data
    csv_data = []
    
    for col_idx, column in enumerate(columns):
        column_num = col_idx + 1
        grid = "A" if column_num % 2 == 1 else "B"
        
        for row_idx, (x, y) in enumerate(column):
            csv_data.append({
                "grid": grid,
                "column": column_num,
                "row": row_idx + 1,
                "x": x,
                "y": y
            })
    
    # Save as CSV
    df = pd.DataFrame(csv_data)
    csv_filename = f"{output_prefix}_dots.csv"
    df.to_csv(csv_filename, index=False)
    print(f"Saved CSV file: {csv_filename}")
    
    # Print summary
    print(f"\nSummary:")
    print(f"  Grid A: {len(gridA_points)} points")
    print(f"  Grid B: {len(gridB_points)} points")
    print(f"  Total: {len(gridA_points) + len(gridB_points)} points")
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

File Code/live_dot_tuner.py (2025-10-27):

#!/usr/bin/env python3
"""
Live Dot Detection Tuner

A real-time GUI application for tuning blob detection parameters on calibration images.
Allows interactive adjustment of detection parameters with immediate visual feedback.

"""

import cv2
import numpy as np
import tkinter as tk
from tkinter import ttk, filedialog, messagebox
import matplotlib.pyplot as plt
from matplotlib.backends.backend_tkagg import FigureCanvasTkAgg
from matplotlib.figure import Figure
import argparse
import os
import sys
import time
from typing import Tuple, List, Optional


class LiveDotTuner:
    def __init__(self, image_path: str):
        self.image_path = image_path
        self.original_image = None
        self.binary_image = None
        self.detected_dots = []
        
        # Load and preprocess image
        self.load_image()
        
        # Initialize GUI
        self.root = tk.Tk()
        self.root.title("Live Dot Detection Tuner")
        self.root.geometry("1400x800")
        
        # Parameter variables for HoughCircles
        self.hough_min_dist = tk.IntVar(value=25)
        self.hough_param1 = tk.IntVar(value=50)
        self.hough_param2 = tk.IntVar(value=15)
        self.hough_min_radius = tk.IntVar(value=9)
        self.hough_max_radius = tk.IntVar(value=17)
        
        # White center filtering threshold
        self.white_threshold = tk.IntVar(value=180)

        # GUI elements
        self.setup_gui()
        
        # Initial detection
        self.update_detection()
    
    def load_image(self):
        """Load and preprocess the calibration image."""
        if not os.path.exists(self.image_path):
            messagebox.showerror("Error", f"Image file not found: {self.image_path}")
            sys.exit(1)
        
        self.original_image = cv2.imread(self.image_path)
        if self.original_image is None:
            messagebox.showerror("Error", f"Could not load image: {self.image_path}")
            sys.exit(1)
        
        # Preprocess image (same as main script)
        gray = cv2.cvtColor(self.original_image, cv2.COLOR_BGR2GRAY)
        blurred = cv2.GaussianBlur(gray, (5, 5), 0)
        self.binary_image = cv2.adaptiveThreshold(
            blurred, 255, cv2.ADAPTIVE_THRESH_GAUSSIAN_C, cv2.THRESH_BINARY, 5, 2
        )
        
        # Morphological operations
        kernel = cv2.getStructuringElement(cv2.MORPH_ELLIPSE, (3, 3))
        self.binary_image = cv2.morphologyEx(self.binary_image, cv2.MORPH_OPEN, kernel)
        self.binary_image = cv2.morphologyEx(self.binary_image, cv2.MORPH_CLOSE, kernel)
        
        print(f"Loaded image: {self.image_path} with shape {self.original_image.shape}")
    
    def setup_gui(self):
        """Setup the GUI layout with controls and image display."""
        # Main frame
        main_frame = ttk.Frame(self.root)
        main_frame.pack(fill=tk.BOTH, expand=True, padx=10, pady=10)
        
        # Left panel for controls
        control_frame = ttk.LabelFrame(main_frame, text="Detection Parameters", padding=10)
        control_frame.pack(side=tk.LEFT, fill=tk.Y, padx=(0, 10))
        
        # Parameter controls
        self.create_parameter_controls(control_frame)
        
        # Right panel for image display
        display_frame = ttk.Frame(main_frame)
        display_frame.pack(side=tk.RIGHT, fill=tk.BOTH, expand=True)
        
        # Create matplotlib figure
        self.fig = Figure(figsize=(10, 8), dpi=100)
        self.ax = self.fig.add_subplot(111)
        
        # Canvas for matplotlib figure
        self.canvas = FigureCanvasTkAgg(self.fig, master=display_frame)
        self.canvas.draw()
        self.canvas.get_tk_widget().pack(fill=tk.BOTH, expand=True)
    
    def create_parameter_controls(self, parent):
        """Create parameter control buttons for HoughCircles detection."""
        # Minimum Distance
        self.create_parameter_group(parent, "Min Distance Between Centers (px)", 
                                   self.hough_min_dist, 5, 100, 1, 5)
        
        # Param1 (Edge Detection Threshold)
        self.create_parameter_group(parent, "Param1 - Edge Threshold", 
                                   self.hough_param1, 10, 200, 1, 10)
        
        # Param2 (Accumulator Threshold)
        self.create_parameter_group(parent, "Param2 - Circle Threshold", 
                                   self.hough_param2, 5, 100, 1, 5)
        
        # Minimum Radius
        self.create_parameter_group(parent, "Minimum Circle Radius (px)", 
                                   self.hough_min_radius, 1, 50, 1, 5)
        
        # Maximum Radius
        self.create_parameter_group(parent, "Maximum Circle Radius (px)", 
                                   self.hough_max_radius, 5, 100, 1, 5)
        
        # White Center Threshold
        self.create_parameter_group(parent, "White Center Threshold (0-255)", 
                                   self.white_threshold, 100, 255, 5, 20)
        
        # Detection info
        ttk.Separator(parent, orient=tk.HORIZONTAL).pack(fill=tk.X, pady=15)
        ttk.Label(parent, text="Detection Results", font=("Arial", 10, "bold")).pack(anchor=tk.W)
        
        self.dots_count_label = ttk.Label(parent, text="Dots detected: 0", font=("Arial", 11))
        self.dots_count_label.pack(anchor=tk.W, pady=(5, 0))
        
        self.detection_info_label = ttk.Label(parent, text="Total circles: 0, White centers: 0", 
                                             font=("Arial", 9), foreground="gray")
        self.detection_info_label.pack(anchor=tk.W, pady=(2, 0))
        
        self.target_label = ttk.Label(parent, text="Target: 264 white dots", foreground="blue")
        self.target_label.pack(anchor=tk.W)
        
        # Quick preset buttons
        ttk.Separator(parent, orient=tk.HORIZONTAL).pack(fill=tk.X, pady=10)
        ttk.Label(parent, text="Quick Presets", font=("Arial", 10, "bold")).pack(anchor=tk.W)
        
        preset_frame = ttk.Frame(parent)
        preset_frame.pack(fill=tk.X, pady=5)
        
        ttk.Button(preset_frame, text="Default", command=self.preset_default).pack(side=tk.LEFT, padx=(0, 5))
        ttk.Button(preset_frame, text="Strict", command=self.preset_strict).pack(side=tk.LEFT, padx=2)
        ttk.Button(preset_frame, text="Lenient", command=self.preset_lenient).pack(side=tk.LEFT, padx=(5, 0))
        
        # Parameter explanation
        ttk.Separator(parent, orient=tk.HORIZONTAL).pack(fill=tk.X, pady=10)
        
        info_frame = ttk.LabelFrame(parent, text="Parameter Guide", padding=5)
        info_frame.pack(fill=tk.X, pady=5)
        
        info_text = (
            "• Min Distance: Prevents multiple detections per dot\n"
            "• Param1: Lower = more edges detected\n" 
            "• Param2: Lower = more circles accepted\n"
            "• Radius: Range of expected dot sizes\n"
            "• White Threshold: Only circles with white centers\n"
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

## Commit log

2025-10-25 Add temp file to RPi5 Enclosure
2025-10-25 Add temp file to Camera Enclosure directory
2025-10-25 Add temporary file for Base to Mounting Rail Connector
2025-10-27 Upload File
    Removed rotation analysis and quality assessment code from stereo calibration script.
2025-10-27 Create comprehensive README.md file for stereoscopic camera system
